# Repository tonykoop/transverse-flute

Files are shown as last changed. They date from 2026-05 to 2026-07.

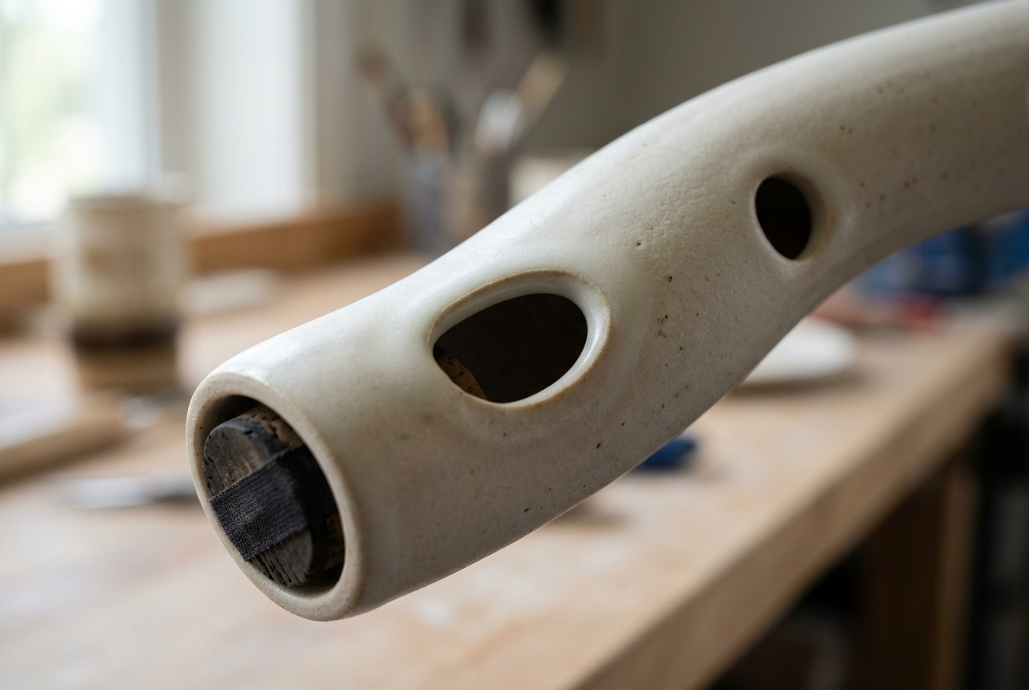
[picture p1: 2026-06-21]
images/macro/embouchure-edge.png

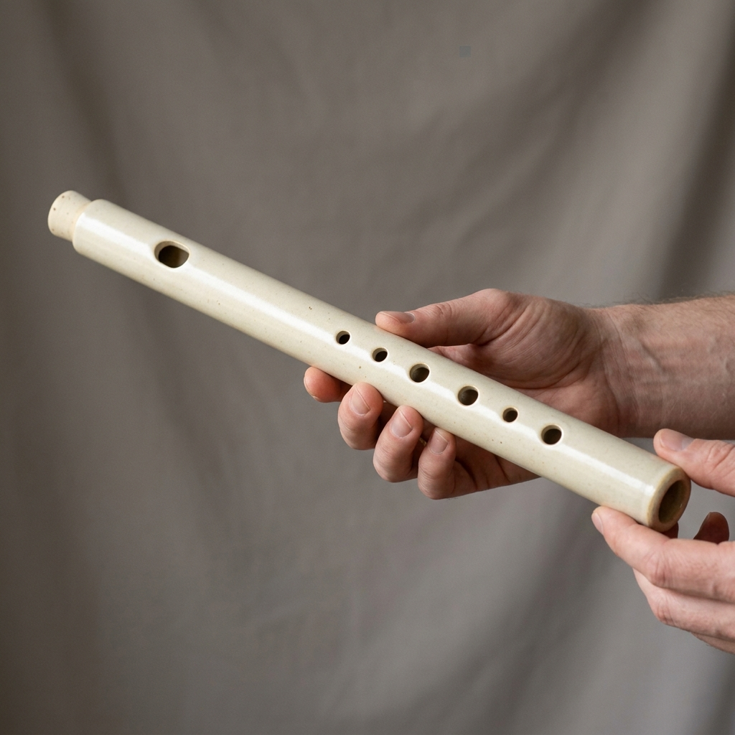
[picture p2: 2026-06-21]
images/hero-render.png

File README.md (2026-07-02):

# Transverse Flute - Experimental Slip-Cast Ceramic Flute Lab

> *A preparatory design repository for a family of slip-cast ceramic transverse flutes - unvalidated, intentionally provisional, and ready to become the project accelerator once materials and shop time arrive.*

Family overview drawing
*First-pass fired target family for D4, F4, G4, A4, and C5. These are planning dimensions, not proven instrument dimensions.*

## What this is

Engineering documentation for an **experimental slip-cast ceramic transverse flute family**. The idea is to start with target final fired dimensions, scale the build masters for X/Y/Z ceramic shrinkage, cast and fire the first round, measure what actually happened, then use those measurements to correct the second round.

This repository is not a finished portfolio of validated instruments yet. It is creative preparatory space: an accelerator, launchpad, laboratory notebook, design-control folder, and build packet so the project can move fast once supplies are acquired.

The repository combines:

1. **A parametric design workbook** ([`Slip-Cast-Transverse-Flute-Family.xlsx`](Slip-Cast-Transverse-Flute-Family.xlsx)) with fired target dimensions, provisional master scaling, tone-hole schedules, a DoE matrix, measurement tables, and shrink-factor fitting sheets.
2. **A Round 1 design-of-experiments plan** ([`doe-plan.md`](doe-plan.md)) for comparing clay bodies, wall targets, bore profiles, embouchure geometry, and mold/drain orientation.
3. **Shop-facing build documentation**: [`design.md`](design.md), [`mold-workflow.md`](mold-workflow.md), [`assembly-manual.md`](assembly-manual.md), [`validation.csv`](validation.csv), [`bom.csv`](bom.csv), [`sourcing.csv`](sourcing.csv), and [`supplier-rfq.md`](supplier-rfq.md).
4. **Drawings and starter CAD** in [`drawings/`](drawings/), [`cad/`](cad/), and [`cnc/`](cnc/) so the first physical work can move from sketch to master/mold planning without starting from a blank page.

Sister project to [`flutes`](https://github.com/tonykoop/flutes), [`fujara`](https://github.com/tonykoop/fujara), [`didgeridoo`](https://github.com/tonykoop/didgeridoo), [`tongue-drum`](https://github.com/tonykoop/tongue-drum), and the broader instrument workshop documentation in this GitHub folder.

## Status and validation warning

**Status:** L2 V5 build-packet candidate

V5 explorer/build-packet candidate for review; fabrication authority
is limited to first-pass prototype planning tables and the local OpenSCAD body
starter. The packet is **not build-ready as a validated instrument** and is not
L3/L4 measured or runtime-verified.

This design has **not been physically built, tuned, fired, or validated**. The dimensions are first-pass engineering targets based on open-open flute math, ceramic shrinkage assumptions, and Tony's existing flute design-table habits.

Use every number in this repository as one of:

- `target` - what the fired instrument is intended to become,
- `assumption` - what Round 1 is testing,
- `starting point` - what will be corrected after measurement.

The design is ready for preparation, quoting, sourcing, CAD cleanup, mold planning, and experimental setup. It is not ready to be treated as a proven flute recipe.

## Background - why slip casting changes the flute problem

A transverse flute is an open-open air column excited by a player blowing across an embouchure edge. In a wooden or metal flute, the maker can usually machine the bore and holes directly to final dimensions, then tune by controlled cutting, undercutting, or keywork adjustments.

Slip-cast ceramic adds a different engineering loop:

- the model/master is not the final size,
- wet clay, bone-dry clay, bisque, and glaze-fired ceramic each move differently,
- X/Y/Z shrinkage may not be equal,
- long thin tubes can sag or ovalize,
- wall buildup changes tone-hole chimney height,
- glaze can damage acoustic edges if it enters the embouchure, bore, or holes.

That makes this project a natural fit for a measured iteration cycle. Round 1 is mostly about learning the clay/process correction factors. Round 2 is where the design becomes more serious.

## Governing acoustic model

First-pass model:

```text
f = c / (2 * L_eff)
L_acoustic = c / (2 * f)
end_correction_total ~= 0.6 * bore_ID
sounding_length ~= L_acoustic - end_correction_total
hole_distance_from_foot ~= L_acoustic * (fundamental_frequency / hole_frequency)
```

This is enough to create a rational starting family, not enough to declare success. Embouchure shape, hole chimney height, wall thickness, bore roundness, stopper position, undercutting, and ceramic surface quality will all move the real instrument.

## The first design family

| ID | Key | Role | Fired pre-trim length | Initial master X @ 12% shrink |
| --- | --- | --- | ---: | ---: |
| SCF-D4-01 | D4 | Low reference / long-body risk case | 24.247 in | 27.554 in |
| SCF-F4-01 | F4 | Family interpolation check | 20.505 in | 23.301 in |
| SCF-G4-01 | G4 | Middle reference / likely first practical prototype | 18.388 in | 20.895 in |
| SCF-A4-01 | A4 | Family interpolation check | 16.432 in | 18.673 in |
| SCF-C5-01 | C5 | Soprano / short-body response check | 13.911 in | 15.808 in |

The detailed target table is in [`data/fired-dimension-targets.csv`](data/fired-dimension-targets.csv). The first-pass hole schedule is in [`data/hole-schedule.csv`](data/hole-schedule.csv).

## Shrinkage model

Coordinate convention:

- X = flute length, bore axis, embouchure station, and tone-hole stations.
- Y = side-to-side bore/OD width and horizontal hole dimensions.
- Z = vertical bore/OD height, wall buildup direction, sag, and ovalization.

The workbook starts at a deliberately provisional 12% shrink in each axis:

```text
master_x = fired_target_x / (1 - shrink_x)
master_y = fired_target_y / (1 - shrink_y)
master_z = fired_target_z / (1 - shrink_z)
observed_shrink_axis = 1 - fired_measured_axis / master_measured_axis
round2_master_axis = round1_master_axis * fired_target_axis / fired_measured_axis
```

Those values are placeholders until fired test bars, bore rings, and flute bodies are measured.

## Round 1 DoE

Round 1 is a screening study, not a production batch. It varies:

- key/scale: D4, G4, and C5 screening with F4/A4 family fill-ins,
- clay body: cone 6 stoneware and cone 6 porcelain,
- wall target: thin, nominal, and thick drain conditions,
- bore profile: cylindrical and mild taper,
- embouchure geometry: standard oval and longer oval,
- mold/drain orientation: horizontal and vertical.

Primary responses:

- X/Y/Z shrink,
- bore roundness and wall thickness,
- crack/warp/sag/seam outcomes,
- fundamental and scale-note cents error,
- octave response and breath threshold,
- subjective playability and tonal stability.

The run matrix is in [`data/doe-build-matrix.csv`](data/doe-build-matrix.csv).

## Engineering challenges this repository is meant to capture

**1. Translating additive-manufacturing shrink intuition into ceramic slip casting.** The project deliberately separates target fired dimensions from master dimensions, then treats X/Y/Z shrink as measured process data rather than a fixed catalog value.

**2. Keeping the acoustic model honest.** Open-open flute math gives the starting geometry, but ceramic flute behavior will be corrected from measured prototypes. The validation sheets are as important as the design table.

**3. Designing for a fragile long body before the materials are on hand.** The D4 body is long enough that mold strategy, drying support, seam cleanup, and bore ovalization are major design concerns before a single note is played.

**4. Creating a repository that becomes useful the moment supplies arrive.** This repo is the setup work: BOM, sourcing, RFQ, shop sequence, drawings, CAD starter, DoE protocol, and measurement schema.

## How to use this repository

Start here:

- [`print-packet.html`](print-packet.html) - browser-friendly combined packet for reading or printing.
- [`Slip-Cast-Transverse-Flute-Family.xlsx`](Slip-Cast-Transverse-Flute-Family.xlsx) - the parametric workbook and measurement hub.
- [`design.md`](design.md) - the compact engineering brief.
- [`doe-plan.md`](doe-plan.md) - the experimental plan.
- [`mold-workflow.md`](mold-workflow.md) - the slip-casting control plan.
- [`assembly-manual.md`](assembly-manual.md) - shop sequence from master through final validation.

Then, once supplies are acquired:

1. Date-check suppliers and update [`sourcing.csv`](sourcing.csv).
2. Pick the first Round 1 run from [`data/doe-build-matrix.csv`](data/doe-build-matrix.csv).
3. Make and measure the master.
4. Cast shrink bars, bore rings, and the flute body together.
5. Record measurements in [`data/prototype-measurements.csv`](data/prototype-measurements.csv).
6. Fit Round 2 corrections in [`data/shrinkage-fit.csv`](data/shrinkage-fit.csv).

## Repository structure

```text
transverse-flute/
|-- README.md
|-- LICENSE                    <- CC-BY 4.0
|-- Slip-Cast-Transverse-Flute-Family.xlsx
|-- design.md
|-- doe-plan.md
|-- mold-workflow.md
|-- assembly-manual.md
|-- bom.csv
|-- sourcing.csv
|-- supplier-rfq.md
|-- validation.csv
|-- cut-list.csv
|-- print-packet.md / print-packet.html
|-- capstone-deck.md
|-- data/
|   |-- fired-dimension-targets.csv
|   |-- hole-schedule.csv
|   |-- doe-build-matrix.csv
|   |-- prototype-measurements.csv
|   `-- shrinkage-fit.csv
|-- drawings/
|   |-- family-overview.svg
|   |-- mold-stack.svg
|   `-- SCF-*-body.svg
|-- cad/
|   `-- slip_cast_transverse_flute_body.scad
|-- cnc/
|   `-- master-fabrication-plan.md
|-- evolution/
|   |-- master/manifest.json
|   |-- design-intent.md
|   `-- revisions.md      <- Stage 0 evolution-pipeline intake (Gate A not yet run)
`-- scripts/
    `-- generate_packet.py
```

## Status

| Section | Status |
| --- | --- |
| Repo description and CC-BY license | done |
| Parametric workbook | first-pass generated |
| Fired target dimension table | first-pass generated |
| Tone-hole schedule | first-pass generated |
| Round 1 DoE plan | drafted |
| Mold workflow | drafted |
| Shop assembly manual | drafted |
| CAD body starter | preliminary OpenSCAD concept |
| Manufacturing drawings | SVG review drawings only |
| V5 family spec | added; open-open / both-ends-open assumptions explicit |
| Visual authority register | added; generated/concept outputs are not fabrication authority |
| MCP provenance log | present; no live MCP sessions were run for this lane |
| Evolution-pipeline intake | Stage 0 intake added (manifest, design-intent, revisions); Gate A not yet run |
| Supplier pricing and availability | not checked |
| Physical prototypes | not started |
| Fired shrink validation | no data yet |
| Acoustic validation | no data yet |
| Round 2 correction factors | pending Round 1 |

## License

Released under [CC-BY 4.0](LICENSE) - use freely with attribution. The written documentation, generated design tables, drawings, scripts, and experimental framework in this repository are my own preparatory engineering work. Because the instrument design is unvalidated, reuse should preserve the experimental status and measurement assumptions until physical builds prove otherwise.

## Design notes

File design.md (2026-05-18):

# Slip-Cast Transverse Flute Family Build Packet

## Source And Scope

- Date: `2026-05-02`
- Source workbook inspected: `/mnt/c/Users/Tony/Documents/Claude/Projects/Career/flutes-staging/Flutes-AI.xlsx`
- Relevant sheet: `Irish Flute`, which uses open-open flute math, D4 sanity dimensions, end correction, and 6-hole diatonic placement.
- Ceramic workflow references inspected: `Ocarina`, `Udu Drum Family`, and `vessel-flute-lab` build packets.

This packet is for unkeyed transverse ceramic flute prototypes made by slip casting. The acoustic dimensions below are final fired targets. Master and mold dimensions are scaled from those targets using provisional X/Y/Z shrink factors.

## Design Intent

Build a family across D4, F4, G4, A4, and C5 so the study sees both long-body casting behavior and smaller higher-key behavior. Round 1 is not trying to prove a finished product. It is meant to produce a clean data set:

- actual X/Y/Z fired shrink by material, wall, and mold orientation,
- actual bore roundness and wall buildup,
- pitch and response error against the open-open first-pass model,
- embouchure and bore-profile preferences before Round 2.

## Governing Model

First-pass open-open transverse flute model:

```text
f = c / (2 * L_eff)
L_acoustic = c / (2 * f)
end_correction_total ~= 0.6 * bore_ID
sounding_length ~= L_acoustic - end_correction_total
hole_distance_from_foot ~= L_acoustic * (fundamental_frequency / hole_frequency)
```

The hole positions are first-pass acoustic stations. Ceramic wall thickness, hole chimney height, undercutting, bore ovalization, embouchure geometry, and stopper position will move real pitch. The packet therefore makes hole cuts undersize and expects bisque-stage tuning.

The V5 acoustic-law summary is tracked in [`family-spec.csv`](family-spec.csv).
Every family row declares `acoustic_law=open_open`,
`end_condition=both_ends_open`, and `dimension_provenance=physics_derived`.
Those fields describe the first-pass planning model only; measured prototype
pitch, bore roundness, shrink, and tone-hole correction data are still required
before the dimensions become validated tuning authority.

## Initial Family Targets

| ID | Key | Bore ID | OD | Sounding length | Pre-trim fired length | Master X length @12% |
| --- | --- | ---: | ---: | ---: | ---: | ---: |
| SCF-D4-01 | D4 | 0.748 in | 1.028 in | 22.625 in | 24.247 in | 27.554 in |
| SCF-F4-01 | F4 | 0.669 in | 0.939 in | 19.001 in | 20.505 in | 23.301 in |
| SCF-G4-01 | G4 | 0.669 in | 0.929 in | 16.885 in | 18.388 in | 20.895 in |
| SCF-A4-01 | A4 | 0.591 in | 0.841 in | 15.045 in | 16.432 in | 18.673 in |
| SCF-C5-01 | C5 | 0.512 in | 0.742 in | 12.643 in | 13.911 in | 15.808 in |

## Shrinkage Model

Coordinate convention:

- X = flute length/bore axis/hole stations.
- Y = side-to-side bore and outside width.
- Z = vertical height, wall buildup, and ovalization direction.

```text
master_x = fired_target_x / (1 - shrink_x)
master_y = fired_target_y / (1 - shrink_y)
master_z = fired_target_z / (1 - shrink_z)
observed_shrink_axis = 1 - fired_measured_axis / master_measured_axis
round2_master_axis = round1_master_axis * fired_target_axis / fired_measured_axis
```

Initial assumption is `shrink_x = shrink_y = shrink_z = 0.12`. This is a placeholder, not a material claim.

## Round 1 Success Criteria

- No full-length cracking through drying, bisque, or glaze fire.
- Bore remains measurable and cleanable.
- Embouchure speaks a stable fundamental and octave on at least the G4 or C5 prototypes.
- Hole tuning can be brought within +/-35 cents after bisque without grotesque hole enlargement.
- X/Y/Z shrink measurements have enough consistency to choose Round 2 scale factors.

## Round 2 Decision Path

1. Fit shrink_x, shrink_y, and shrink_z from bars, bore rings, and flute features.
2. Choose the best material/profile/embouchure combination from the DoE.
3. Update the workbook inputs and regenerate master dimensions.
4. Rebuild the full five-key family using corrected X/Y/Z scale factors.
5. Tighten acceptance to +/-10 cents for tuned notes and +/-0.010 to +/-0.030 in on critical fired dimensions.

## Open Assumptions

- Bore diameters are adapted from the existing Irish/simple-system flute design range, then made ceramic-friendly with thinner walls than wood.
- A removable head stopper or cork test plug is assumed for Round 1 because it gives a reversible tuning variable.
- All prices, supplier availability, and exact clay data must be date-checked before buying.
- CAD mold release and split lines need confirmation in the actual CAD model before cutting production molds.

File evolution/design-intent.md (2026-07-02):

# Design Intent — transverse-flute rev A

- Master CAD: `cad/slip_cast_transverse_flute_body.scad` (sha256: 09559ce3695fb347a80539320d67dd08b2f200aac15d973c2522a8109cbf1eda), driven by `Slip-Cast-Transverse-Flute-Family.xlsx` (sha256: 8956d4db48cb64065a868b3e6a1f89d63ca9b68a0c0be8512c7b77fd6ee7f224)
- Function: Experimental slip-cast ceramic transverse flute family (D4/F4/G4/A4/C5). Open-open flute model: both ends open, side-blown embouchure; pitch from sounding length + bore + end corrections. Tone-hole stations are first-pass open-open ratios and require prototype tuning. First-pass workflow: fired target dims → scale masters for shrinkage → cast/fire Round 1 → measure → correct.
- Environment: Cone-6 slip-cast ceramic via master + plaster mold; long thin tubes are warp/crack-prone in firing; shrinkage is an assumption until a clay test bar is measured. Embouchure/voicing geometry is empirical and outside the model.
- Target qty: 1 (Round 1 prototype, G4 first). Deadline: TBD. Budget/unit ceiling: TBD.

## Critical dimensions (carry tolerances)

| Feature | Nominal | Tolerance | Why critical | Source |
| --- | --- | --- | --- | --- |
| G4 packet sounding length | 428.88 mm | tune to pitch after firing | fundamental pitch (G4 = 391.995 Hz) | family-spec.csv SCF-G4-01 (physics_derived) |
| G4 fired bore ID | 16.99 mm | measure after fire | bore governs pitch/response | family-spec.csv SCF-G4-01 (physics_derived) |
| G4 total end correction | 10.19 mm | recompute from measured bore | open-open end effect | family-spec.csv SCF-G4-01 |
| G4 master overall length (initial) | 530.73 mm | recompute from measured shrinkage | fired size vs master | family-spec.csv SCF-G4-01 (first-pass scaling) |
| Tone-hole stations | per data/hole-schedule.csv (first-pass ratios) | undersize; tune post-bisque | scale intonation | data/hole-schedule.csv (measurement_required) |
| A4 reference | 440.000 Hz | ±cents logged in validation.csv | tuning correctness | family-spec.csv SCF-A4-01 |

## Incidental (free for DFM)

- Body exterior styling, decorative banding, glaze color/family, non-mating surface finish, headjoint cosmetic contour.

## Must-nots (DFM may never violate)

- Embouchure/voicing cut is tuning-sensitive: never freeze it from the table or a lossy mesh export — refine by hand and log (risks.md / README).
- Keep tone holes undersized before empirical bisque-stage tuning (data/hole-schedule.csv; risks.md Acoustic).
- Do not treat any dimension as proven until logged in validation.csv; no build/tune/fire has occurred (README validation warning).
- Do not scale to the full family before Round 1 (G4) measured shrinkage + tuning corrections (doe-plan.md / risks.md Structural).

## Material intent

- Preferred: Cone-6 slip-cast ceramic; master + two-piece plaster mold (per bom.csv / mold-workflow.md).
- Acceptable subs: per sourcing.csv / supplier-rfq.md (spec-first; live prices unverified; mouth-safe finishes only).
- Forbidden: non-mouth-safe interior finishes on blown bodies.

## Stage status

Stage 0 intake complete 2026-07-01. Gate A (Alpha shop compile) NOT yet run — no concessions logged, nothing presented as shippable. Design is experimental/unvalidated; fabrication authority remains measurement-gated (L2 candidate for review).

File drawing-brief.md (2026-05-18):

# Drawing Brief

## Required Views

- Family overview showing D4, F4, G4, A4, and C5 fired target lengths.
- Individual body plan view for each key with X-axis datum, embouchure, tone holes, bore ID, OD, and fired/master length notes.
- Section view at embouchure showing wall thickness, bore, hole edge, undercut zone, and stopper relationship.
- Section view through a tone hole showing chimney height and allowed tuning/undercut area.
- Mold stack view showing split line, registration keys, pour/drain direction, seam cleanup zone, and optional three-piece D4 strategy.
- Shrink coupon drawing with X/Y/Z labels and measurement flats.

## Critical Dimensions

| Dimension | Source | Tolerance Intent |
| --- | --- | --- |
| Fired sounding length | `data/fired-dimension-targets.csv` and workbook | Tuning critical |
| Embouchure center from head | workbook, initial 1.5 x bore ID | Response and tuning |
| Bore ID Y/Z | workbook and bore ring measurement | Tuning, response, shrink fit |
| Tone-hole stations X | `data/hole-schedule.csv` | Tuning critical; first-pass only |
| Tone-hole diameters | `data/hole-schedule.csv` | Cut undersize; tune after bisque |
| Wall thickness | DoE wall target and measured coupons | Durability, weight, hole chimney |
| Master X/Y/Z scale | shrink model | Process critical |

## Existing Drawings

- `drawings/family-overview.svg`
- `drawings/mold-stack.svg`
- `drawings/SCF-D4-01-body.svg`
- `drawings/SCF-F4-01-body.svg`
- `drawings/SCF-G4-01-body.svg`
- `drawings/SCF-A4-01-body.svg`
- `drawings/SCF-C5-01-body.svg`

These are SVG shop-review drawings. They are not a substitute for final CAD mold drawings with draft and release analysis.

## V5 Visual Authority

The visual authority chain is tracked in
[`visual-output-register.csv`](visual-output-register.csv). The design tables
and OpenSCAD starter are first-pass prototype fabrication authority for current
planning geometry only. The SVG drawings are derived review previews and must
not be treated as standalone cut-ready DXF/CNC authority. No generated image is
dimensional authority for bore length, embouchure geometry, tone-hole position,
wall thickness, mold split lines, or toolpaths.

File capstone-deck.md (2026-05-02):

# Slip-Cast Transverse Flute Family
- Musical instrument documentation capstone
- Packet: /mnt/c/Users/Tony/Documents/GitHub/transverse-flute
- Generated: 2026-05-02

---

# How To Use This Packet
- Start with design.md for intent and assumptions.
- Use bom.csv, sourcing.csv, and cut-list.csv before buying or cutting.
- Use drawing-brief.md and CAD/CNC folders before machining.
- Print the packet for shopping, shop work, and validation.

---

# File Map
- design.md: Project intent, catalog metadata, assumptions, and validation plan.
- bom.csv: Starter bill of materials with part categories, quantities, drawing refs, and notes.
- sourcing.csv: Supplier/search tracker with specs, price/date fields, lead time, substitutes, and risks.
- cut-list.csv: Rough/final stock sizes, material, grain/orientation, operations, yield, and offcuts.
- drawing-brief.md: Manufacturing drawing and technical product sketch brief.
- assembly-manual.md: Shop-facing sequence, tools, fixtures, safety, tuning, finishing, and maintenance notes.
- validation.csv: Target/measured values, tolerance, environment, result, and tuning/build action log.
- supplier-rfq.md: Supplier email/request-for-quote starter.

---

# Build Workflow
- Design and assumptions
- Source materials and hardware
- Prepare stock, fixtures, and CNC/laser/lathe setup
- Assemble, tune, finish, and validate

---

# Sourcing And BOM
- BOM gives part categories and drawing references.
- Sourcing tracks search terms, supplier candidates, price/date, lead time, and substitutions.
- Visual BOM brief turns the parts list into a presentation-ready image board.

---

# Shop Packet
- Cut list for lumber/sheet/blank planning.
- Assembly manual for away-from-keyboard work.
- Validation sheet for measured dimensions, tuning, and pass/fail checks.

---

# Drawings, CAD, CNC
- drawing-brief.md defines required views, dimensions, datums, and sketch intent.
- cad/ holds models and design tables.
- cnc/ holds CAM, toolpaths, setup sheets, and dry-run notes.
- drawings/ holds PDFs, SVGs, DXFs, and drawing exports.

---

# Images And Screenshots
- Add hero render/photo, visual BOM, shop screenshots, drawing previews, and validation photos in images/.

---

# Next Actions
- Replace TBDs with measured/source-backed values.
- Verify live supplier price and availability before buying.
- Export final drawings and visual BOM images.
- Regenerate this deck and print packet after final edits.

---

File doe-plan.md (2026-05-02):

# Round 1 DoE Plan

## Purpose

Round 1 is a screening study for a slip-cast transverse flute family. It should answer:

- What are the actual X/Y/Z shrink factors for each clay/process condition?
- Which clay body and wall target survive long flute geometry?
- Does a cylindrical bore or mild taper give better response after ceramic firing?
- Which embouchure geometry speaks cleanly before excessive hand correction?
- Do shrink and acoustic errors interpolate across D4, G4, and C5 well enough to build F4 and A4 in Round 2?

## Factors

| Factor | Levels |
| --- | --- |
| Key/scale | D4, G4, C5 screening; F4 and A4 family fill-ins |
| Clay body | Cone 6 stoneware, Cone 6 porcelain |
| Wall target | thin drain, nominal drain, thick drain |
| Bore profile | cylindrical, mild taper |
| Embouchure | standard oval, longer oval |
| Mold orientation | horizontal drain, vertical drain |

## Responses

- X/Y/Z shrink from bars, bore rings, and flute features.
- Bore roundness: fired ID Y vs ID Z.
- Wall thickness at head, middle, foot.
- Fundamental and six-finger scale cents error.
- Octave response, breath threshold, tone stability, and subjective playability.
- Crack/warp/sag/seam cleanup outcomes.

## Round 1 Matrix

See `data/doe-build-matrix.csv`. It contains 20 planned runs including screening and family fill-in builds.

## Round 2 Fit

Use `data/prototype-measurements.csv` and `data/shrinkage-fit.csv` to compute:

```text
shrink_axis = 1 - fired_axis / master_axis
round2_axis_scale_multiplier = target_fired_axis / measured_fired_axis
cents_error = 1200 * log2(measured_frequency / target_frequency)
```

If material or orientation creates a strong interaction, keep separate shrink factors by material/orientation rather than forcing a single global X/Y/Z value.

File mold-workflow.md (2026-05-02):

# Slip-Cast Mold Workflow

## Master Strategy

1. Generate the master from the workbook/CAD dimensions using X/Y/Z scale factors.
2. Add external handling tabs, pour/drain reservoir geometry, and mold keys outside the final fired acoustic envelope.
3. Seal and polish the master. Measure master X/Y/Z dimensions before making plaster.
4. Mark datums permanently: head end, foot end, top/embouchure side, X/Y/Z axes, split line, and build ID.

## Mold Strategy

- Use a two-piece mold for G4/A4/C5 if release is clean.
- Consider a three-piece or sectional mold for D4 because length, sag, and demold stress are the main risks.
- Mold center marks or shallow dimples for holes are useful; avoid fully molded tone holes in Round 1 unless release testing proves they are clean.
- Keep registration keys away from the bore axis, embouchure edge, hole centers, and seam-cleanup surfaces.
- Include a pour/drain reservoir that can be removed without touching the fired trim target.

## Casting Controls

Record these for every run:

- slip body and batch,
- mold dry weight and mold age,
- pour time, drain time, and drain orientation,
- room temperature and humidity,
- leather-hard demold time,
- wall thickness at sacrificial rim/coupon,
- dry, bisque, and glaze firing schedules,
- fired mass, length, bore Y/Z, OD Y/Z, and note frequencies.

## Tuning-Friendly Hole Strategy

1. Cast the body with molded center marks only.
2. Cut pilot holes at leather hard, about 85% of the shrink-compensated target diameter.
3. Dry and bisque.
4. Tune by opening holes with diamond tools. Stop before final glaze.
5. Wax resist all acoustic edges before glaze.

## Failure Modes To Watch

- Long D4 body sags or twists while drying.
- Bore ovalizes differently in Y and Z.
- Mold seam intrudes into the embouchure or tone-hole region.
- Wall thickness drifts with drain time enough to change hole chimney height.
- Glaze softens, rounds, or chokes the embouchure and tone-hole edges.

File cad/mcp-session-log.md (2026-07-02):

# MCP Session Log

This log is intentionally present for the V5 provenance contract. No live MCP
tool sessions were run in this Round 30 lane, so no generated render, Adobe,
Blender, Illustrator, Photoshop, or image-gen artifact is claimed here.

| timestamp_utc | mcp_tool | session_id | artifact | parent_artifact | authority_role | notes |
| --- | --- | --- | --- | --- | --- | --- |
| 2026-05-18T00:00:00Z | none | not-run-round30 | cad/slip_cast_transverse_flute_body.scad | data/fired-dimension-targets.csv | local-cad-starter | Existing OpenSCAD starter reconciled to the G4 first-pass target; not a measured or runtime-generated MCP artifact. |
| 2026-07-01T00:00:00Z | claude-code (Fable 5) | fable-v5-refresh-2026-07-01 | Slip-Cast-Transverse-Flute-Family.xlsx, data/hole-schedule.csv, data/fired-dimension-targets.csv | Slip-Cast-Transverse-Flute-Family.xlsx | packet_refresh (authority_result=fabrication, review_status=self_checked) | V5 refresh pass; tabular packet data (workbook + hole schedule + fired-dimension targets) reviewed against design table. No dimension changes made. Provenance rows added to satisfy V5 fabrication-artifact logging. |
| 2026-07-01T00:00:00Z | claude-code (Fable 5) + OpenSCAD CLI | fable-v5-refresh-2026-07-01 | cad/slip_cast_transverse_flute_body.scad | data/fired-dimension-targets.csv | cad_authoring (authority_result=pending_measurement, review_status=self_checked) | Existing parametric body-envelope master (kept, not rewritten). openscad render check: pass (openscad -o STL, exit 0). |
| 2026-07-01T00:00:00Z | claude-code (Fable 5) | fable-v5-refresh-2026-07-01 | transverse-flute-starter.wl | Slip-Cast-Transverse-Flute-Family.xlsx | analysis_source (authority_result=derived_preview, review_status=unreviewed) | Wolfram/physics starter; source-only (not executed). L2 evidence. |

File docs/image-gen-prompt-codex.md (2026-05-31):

# Image Generation Prompt

Concept image only; not fabrication authority. Do not include cut-ready dimensions, hole locations, mold split dimensions, or toolpaths.

## Hero Prompt

Photorealistic 3/4 studio product photograph of an experimental slip-cast ceramic transverse flute family, unkeyed and open-hole, with D4, F4, G4, A4, and C5 prototypes arranged from longest to shortest. Show smooth fired ceramic bodies with subtle stoneware and porcelain glaze variations, oval embouchure holes, undersize tone holes, removable stopper cues, and faint mold seam cleanup consistent with a lab prototype. Clean neutral background, soft directional studio lighting, realistic fragile ceramic scale cues, high detail, 50mm lens look.

## In-Context Prompt

Photorealistic ceramic studio scene with slip-cast transverse flute prototypes on a ware board beside plaster molds, shrinkage test bars, bore rings, calipers, clay slip container, and a tuning notebook. Natural studio light, practical experimental mood, showing the project as a fired-dimension and shrinkage study rather than a finished production flute line.

## Detail / Macro Prompt

Macro photorealistic close-up of a ceramic transverse flute embouchure: smooth oval cut, fired clay wall thickness, subtle glaze edge kept out of the acoustic opening, faint mold seam cleanup, and a nearby undersize tone hole. Use shallow depth of field, realistic ceramic texture, and no dimensional marks.

## Negative / Avoid

No text, no watermarks, no brand logos, no extra limbs, anatomically plausible hands if shown, no metal keywork, no impossible glaze inside holes, no hole-location diagrams, no dimensions, no toolpaths.

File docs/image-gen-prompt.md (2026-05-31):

# Image-Gen Prompts

Concept image only; not fabrication authority. Do not include cut-ready dimensions, hole locations, tone-hole spacing, bore diameters, sounding lengths, shrink factors, or toolpaths.

## Hero Prompt

Photorealistic 3/4 product photograph of a finished slip-cast ceramic transverse flute: a single long, slender cylindrical tube held horizontally, open at both ends like a concert flute, its surface the smooth fired glaze of cone-6 stoneware or porcelain with the soft sheen of a kiln-fired clay body rather than wood or metal. The defining feature is the oval embouchure hole set near one end where the player blows across the edge, with a hint of a removable head stopper just beyond it; a single in-line row of round, unkeyed finger tone holes runs down the body, the instrument having no metal keywork at all so it reads as a clean simple-system ceramic flute. The fired ceramic implies a faintly weighty, fragile elegance with a gently rounded bore mouth at each open end, restrained surface with no decoration. Hand-playable flute scale cues, satin glazed ceramic catching soft directional studio light that grazes the curved tube, clean neutral studio background, 3/4 product-photography angle, ~50mm lens, high detail, photorealistic, no text labels. Avoid: no text, logos, watermarks, or fake maker marks, no dimension callouts or cut diagrams, no metal keys or pads, no impossible bends in the tube, no glaze flooding the embouchure or tone holes. IMPORTANT: This image is a concept visualization only. Do not include dimension lines, measurements, or fabrication specifications. The image is not authoritative for any physical build dimension.

## In-Context Prompt

Photorealistic image of the slip-cast ceramic transverse flute family staged on a quiet ceramic-studio bench: five finished fired flutes of graduated length fanned in a row from the longest low-D body down to the short soprano-C body, arranged like a tonal scale, beside a plaster mold half, a couple of small fired shrink-test coupons and a bore ring, and a chromatic tuner with a clip mic for storytelling. Natural window light rakes across the glazed tubes; a maker's hands hover above the middle flute as if checking the embouchure against the tuner, the longest body resting on a felt pad so its slender fragility reads clearly. Warm workshop atmosphere, dusty plaster and clay tones in the background, realistic fired-ceramic materials, shallow depth of field, concept visualization only. Avoid: no text, logos, watermarks, or fake maker marks, no dimension callouts, no metal keywork, no impossible mechanisms; anatomically plausible hands with natural finger placement over the tone holes. IMPORTANT: This image is a concept visualization only. Do not include dimension lines, measurements, or fabrication specifications. The image is not authoritative for any physical build dimension.

## Detail Prompt

Photorealistic macro close-up of the signature mechanism: the oval embouchure hole of the ceramic flute where the player blows across a crisp acoustic edge, the fired glaze sweeping smoothly into the cleanly cut hole with no glaze pooling on the edge, the subtle shadow of the bore and a hint of the removable head stopper visible just inside the open end, one or two round unkeyed tone holes blurring into the body beyond. Satin glazed cone-6 ceramic texture with faint kiln character, the curved wall of the tube catching soft raking light that reveals the rounded mouth of the open end and the chimney of the tone hole through the wall thickness. Shallow depth of field, high detail, no measurements. Avoid: no text, logos, watermarks, or fake maker marks, no dimension callouts, no metal keys or pads, no impossible edges, no glaze flooding the embouchure. IMPORTANT: This image is a concept visualization only. Do not include dimension lines, measurements, or fabrication specifications. The image is not authoritative for any physical build dimension.

## Negative / Avoid

No text, logos, watermarks, fake maker marks, cut diagrams, dimension callouts, metal keywork or pads, impossible tube bends, glaze flooding the embouchure or tone holes, extra fingers, or hands covering tone holes unnaturally; anatomically plausible hands if a player is shown.

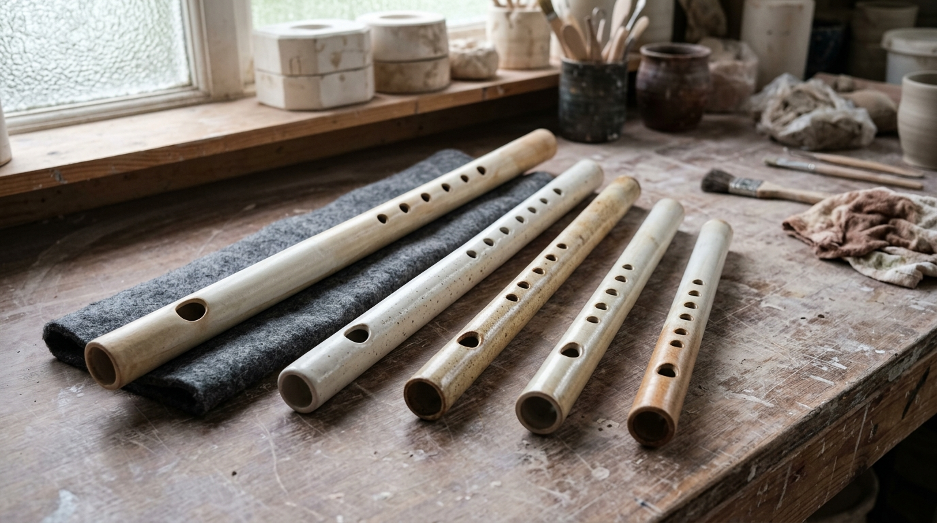
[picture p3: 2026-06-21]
images/family-group.png

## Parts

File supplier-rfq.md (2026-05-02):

# Supplier RFQ Starter

Subject: RFQ - slip-cast ceramic flute prototype materials and master/mold support

Hello,

I am prototyping a family of slip-cast ceramic transverse flutes and need materials or fabrication support with measured shrinkage and repeatability data.

Please quote the following where available:

- Cone 6 stoneware casting slip with shrinkage, absorption, and firing schedule data.
- Cone 6 porcelain casting slip with shrinkage, absorption, and firing schedule data.
- Pottery plaster suitable for slip-casting molds.
- Optional high-resolution master printing or machining for long cylindrical flute masters up to about 29 in master length.

Please include:

- unit price and minimum order,
- current availability and lead time,
- shipping or local pickup options,
- technical data sheets,
- recommended mold/drying/firing notes,
- any substitutions you recommend for thin-walled musical instrument bodies.

The prototypes will be measured for X/Y/Z shrinkage, bore roundness, wall thickness, and acoustic tuning after firing.

Thank you,

Tony

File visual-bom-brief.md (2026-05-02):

# Visual BOM Brief

Create an image-forward BOM plate in Tony's Ashiko BOM style:

- Header: Slip-Cast Transverse Flute Family, quote date, material status, and Round 1 / Round 2 label.
- Hero image: family fan of the five fired target flutes or a clean CAD render.
- Table rows grouped by CAD/master, mold, ceramic material, tuning tools, validation tools, and finishing.
- Include thumbnails for: master, plaster mold halves, casting slip, shrink bars, bore rings, diamond files, tuner/mic, cork/stopper kit.
- Add callouts showing X/Y/Z shrink axes and where measurements are taken.
- Mark generated/CAD imagery as placeholders until replaced with shop photos or supplier images.

Important: the visual BOM should communicate process and parts, not invent unverified dimensions. Pull all numbers from the workbook and CSVs.

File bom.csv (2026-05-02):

item_id | subsystem | item | qty | unit | material_spec | make_buy | drawing_ref | notes
SCF-BOM-001 | CAD/master | Parametric flute body master set | 5 | masters | Sealed 3D print or machined master, scaled by X/Y/Z shrink factors | Make | drawings/SCF-*-body.svg; cad/slip_cast_transverse_flute_body.scad | Use as mold masters or CAD reference. Add mold split before production tooling.
SCF-BOM-002 | Mold | Two-piece or three-piece plaster molds | 5+ | molds | Pottery plaster, registration keys, pour/drain reservoir | Make | drawings/mold-stack.svg | D4 may need sectional mold or reinforced cradle due to length.
SCF-BOM-003 | Material | Cone 6 stoneware casting slip | TBD | gallons | Casting slip with known fired shrinkage and absorption | Buy/mix | data/doe-build-matrix.csv | Date-check supplier and record batch number.
SCF-BOM-004 | Material | Cone 6 porcelain casting slip | TBD | gallons | Porcelain slip for comparison runs | Buy/mix | data/doe-build-matrix.csv | Higher shrink/warpage risk, better density and surface.
SCF-BOM-005 | Tuning | Diamond needle files and small diamond burrs | 1 | set | Fine files for bisque and fired ceramic hole tuning | Buy | assembly-manual.md | Avoid glazing acoustic edges after tuning.
SCF-BOM-006 | Validation | Measurement kit | 1 | kit | Calipers, bore gauges/pin gauges, tuner, mic, thermometer/hygrometer, scale | Use/buy | validation.csv | Use the same tuner/mic distance for all response tests.
SCF-BOM-007 | Voicing | Cork/stopper test kit | 5 | sets | Cork, silicone, or printed plug for head-end tuning experiments | Make/buy | drawing-brief.md | Treat head-stopper position as an adjustable variable before ceramic-integral solutions.
SCF-BOM-008 | Finish | Wax resist and glaze test set | 1 | set | Food-safe/contact-safe glaze where mouth contact occurs; acoustic edges waxed clear | Buy | mold-workflow.md | Keep glaze out of embouchure, bore, tone holes, and stopper fit surfaces.

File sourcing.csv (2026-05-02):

source_id | category | spec | supplier_or_search_terms | qty | date_checked | unit_price | lead_time | substitution_rule | risk_notes
SRC-SLIP-STONEWARE | Ceramic slip | Cone 6 stoneware casting slip, published shrinkage and absorption data | local ceramic supplier cone 6 stoneware casting slip shrinkage data sheet | TBD |  |  |  | Must have measured or published shrinkage; color can vary. | Live price and availability intentionally blank until purchase planning.
SRC-SLIP-PORCELAIN | Ceramic slip | Cone 6 porcelain casting slip, low warpage preferred | cone 6 porcelain casting slip shrinkage casting data sheet | TBD |  |  |  | Substitute only with data-backed shrink and firing schedule. | Porcelain may move more; use bars and rings before long D4 molds.
SRC-PLASTER | Mold material | Pottery plaster or high-strength mold plaster | USG pottery plaster No. 1 local ceramic supplier | TBD |  |  |  | Must be absorbent mold plaster, not general patching plaster. | Mold drying time affects casting wall thickness and repeatability.
SRC-PRINT | Master fabrication | High-resolution sealed print or machined master; smooth bore core strategy | SLA print service large format resin smooth finish or in-house FDM sealed master | 5 masters plus coupons |  |  |  | Any method is acceptable if master dimensions are measured and sealed. | Layer lines transfer to plaster and may disturb mold release.
SRC-TUNING | Tuning tools | Diamond needle files, small diamond burrs, tuner/mic | diamond needle file set ceramic tuning burr chromatic tuner measurement microphone | 1 kit |  |  |  | Prefer fine controlled abrasion over aggressive rotary cutting. | Over-opening holes is not reversible.

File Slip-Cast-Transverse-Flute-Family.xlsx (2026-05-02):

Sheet: Inputs
Slip-Cast Transverse Flute Family Inputs
Generated | 2026-05-02
Source basis | Open-open flute model adapted from Tony's Flutes-AI.xlsx Irish Flute sheet
A4_Hz | 440
speed_of_sound_in_per_s_68F | 13552
shrink_x_initial | 0.12 | X axis = bore length and hole stations
shrink_y_initial | 0.12 | Y axis = side-to-side bore/OD and hole width
shrink_z_initial | 0.12 | Z axis = vertical OD/wall/ovalization
round2_rule | new_master_axis = old_master_axis * target_fired_axis / measured_fired_axis

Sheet: Fired Targets
instrument_id | variant | key | midi | fundamental_hz | bore_id_fired_in | wall_fired_in | od_fired_in | acoustic_length_in | end_correction_total_in | sounding_length_in | head_margin_in | foot_trim_band_in | pretrim_overall_fired_in | embouchure_x_len_fired_in | embouchure_y_width_fired_in
SCF-D4-01 | Low D reference | D4 | 62 |  | 0.748 | 0.14 |  |  |  |  |  | 0.5
SCF-F4-01 | F middle | F4 | 65 |  | 0.669 | 0.135 |  |  |  |  |  | 0.5
SCF-G4-01 | G middle | G4 | 67 |  | 0.669 | 0.13 |  |  |  |  |  | 0.5
SCF-A4-01 | A small alto | A4 | 69 |  | 0.591 | 0.125 |  |  |  |  |  | 0.5
SCF-C5-01 | C soprano | C5 | 72 |  | 0.512 | 0.115 |  |  |  |  |  | 0.5

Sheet: Master Scale
instrument_id | master_overall_x_in | master_bore_y_in | master_od_y_in | master_od_z_in | master_emb_x_in | master_emb_y_in | formula_note
SCF-D4-01 |  |  |  |  |  |  | Update Inputs B7:B9 after Round 1 measurement.
SCF-F4-01 |  |  |  |  |  |  | Update Inputs B7:B9 after Round 1 measurement.
SCF-G4-01 |  |  |  |  |  |  | Update Inputs B7:B9 after Round 1 measurement.
SCF-A4-01 |  |  |  |  |  |  | Update Inputs B7:B9 after Round 1 measurement.
SCF-C5-01 |  |  |  |  |  |  | Update Inputs B7:B9 after Round 1 measurement.

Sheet: Hole Schedule
instrument_id | key | hole_no | interval | target_note | target_frequency_hz | fired_center_from_foot_in | fired_center_from_head_in | fired_hole_diameter_in | leather_hard_pilot_dia_in_85pct | notes
SCF-D4-01 | D4 | 1 | 2 | E4 | 329.628 | 20.557 | 3.191 | 0.254 | 0.246 | First-pass station; cut undersize and tune after bisque.
SCF-D4-01 | D4 | 2 | 4 | Gb4 | 369.994 | 18.314 | 5.433 | 0.269 | 0.26 | First-pass station; cut undersize and tune after bisque.
SCF-D4-01 | D4 | 3 | 5 | G4 | 391.995 | 17.286 | 6.461 | 0.284 | 0.275 | First-pass station; cut undersize and tune after bisque.
SCF-D4-01 | D4 | 4 | 7 | A4 | 440 | 15.4 | 8.347 | 0.299 | 0.289 | First-pass station; cut undersize and tune after bisque.
SCF-D4-01 | D4 | 5 | 9 | B4 | 493.883 | 13.72 | 10.027 | 0.322 | 0.311 | First-pass station; cut undersize and tune after bisque.
SCF-D4-01 | D4 | 6 | 11 | Db5 | 554.365 | 12.223 | 11.524 | 0.344 | 0.332 | First-pass station; cut undersize and tune after bisque.
SCF-F4-01 | F4 | 1 | 2 | G4 | 391.995 | 17.286 | 2.719 | 0.227 | 0.22 | First-pass station; cut undersize and tune after bisque.
SCF-F4-01 | F4 | 2 | 4 | A4 | 440 | 15.4 | 4.605 | 0.241 | 0.233 | First-pass station; cut undersize and tune after bisque.
SCF-F4-01 | F4 | 3 | 5 | Bb4 | 466.164 | 14.536 | 5.469 | 0.254 | 0.246 | First-pass station; cut undersize and tune after bisque.
SCF-F4-01 | F4 | 4 | 7 | C5 | 523.251 | 12.95 | 7.055 | 0.268 | 0.258 | First-pass station; cut undersize and tune after bisque.
SCF-F4-01 | F4 | 5 | 9 | D5 | 587.33 | 11.537 | 8.468 | 0.288 | 0.278 | First-pass station; cut undersize and tune after bisque.
SCF-F4-01 | F4 | 6 | 11 | E5 | 659.255 | 10.278 | 9.727 | 0.308 | 0.297 | First-pass station; cut undersize and tune after bisque.
SCF-G4-01 | G4 | 1 | 2 | A4 | 440 | 15.4 | 2.488 | 0.227 | 0.22 | First-pass station; cut undersize and tune after bisque.
SCF-G4-01 | G4 | 2 | 4 | B4 | 493.883 | 13.72 | 4.168 | 0.241 | 0.233 | First-pass station; cut undersize and tune after bisque.
SCF-G4-01 | G4 | 3 | 5 | C5 | 523.251 | 12.95 | 4.938 | 0.254 | 0.246 | First-pass station; cut undersize and tune after bisque.
SCF-G4-01 | G4 | 4 | 7 | D5 | 587.33 | 11.537 | 6.351 | 0.268 | 0.258 | First-pass station; cut undersize and tune after bisque.
SCF-G4-01 | G4 | 5 | 9 | E5 | 659.255 | 10.278 | 7.61 | 0.288 | 0.278 | First-pass station; cut undersize and tune after bisque.
SCF-G4-01 | G4 | 6 | 11 | Gb5 | 739.989 | 9.157 | 8.731 | 0.308 | 0.297 | First-pass station; cut undersize and tune after bisque.
SCF-A4-01 | A4 | 1 | 2 | B4 | 493.883 | 13.72 | 2.212 | 0.201 | 0.194 | First-pass station; cut undersize and tune after bisque.
SCF-A4-01 | A4 | 2 | 4 | Db5 | 554.365 | 12.223 | 3.709 | 0.213 | 0.206 | First-pass station; cut undersize and tune after bisque.
SCF-A4-01 | A4 | 3 | 5 | D5 | 587.33 | 11.537 | 4.395 | 0.225 | 0.217 | First-pass station; cut undersize and tune after bisque.
SCF-A4-01 | A4 | 4 | 7 | E5 | 659.255 | 10.278 | 5.654 | 0.236 | 0.228 | First-pass station; cut undersize and tune after bisque.
SCF-A4-01 | A4 | 5 | 9 | Gb5 | 739.989 | 9.157 | 6.775 | 0.254 | 0.245 | First-pass station; cut undersize and tune after bisque.
SCF-A4-01 | A4 | 6 | 11 | Ab5 | 830.609 | 8.158 | 7.774 | 0.272 | 0.263 | First-pass station; cut undersize and tune after bisque.
SCF-C5-01 | C5 | 1 | 2 | D5 | 587.33 | 11.537 | 1.874 | 0.174 | 0.168 | First-pass station; cut undersize and tune after bisque.
SCF-C5-01 | C5 | 2 | 4 | E5 | 659.255 | 10.278 | 3.132 | 0.184 | 0.178 | First-pass station; cut undersize and tune after bisque.
SCF-C5-01 | C5 | 3 | 5 | F5 | 698.456 | 9.701 | 3.709 | 0.195 | 0.188 | First-pass station; cut undersize and tune after bisque.
SCF-C5-01 | C5 | 4 | 7 | G5 | 783.991 | 8.643 | 4.768 | 0.205 | 0.198 | First-pass station; cut undersize and tune after bisque.
SCF-C5-01 | C5 | 5 | 9 | A5 | 880 | 7.7 | 5.711 | 0.22 | 0.213 | First-pass station; cut undersize and tune after bisque.
SCF-C5-01 | C5 | 6 | 11 | B5 | 987.767 | 6.86 | 6.551 | 0.236 | 0.227 | First-pass station; cut undersize and tune after bisque.

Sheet: DoE Matrix
run_id | phase | instrument_id | clay_body | wall_target | bore_profile | embouchure_geometry | mold_orientation | replicate | primary_response | decision_rule
SCF-R1-01 | Round 1 screening | SCF-D4-01 | Cone 6 stoneware | thin drain | cylindrical | round/standard oval | horizontal drain | screening | X/Y/Z shrink, playable response, cents error | Keep if no cracks, first octave speaks, median cents abs <= 35 after bisque tune.
SCF-R1-02 | Round 1 screening | SCF-D4-01 | Cone 6 stoneware | nominal drain | mild taper | long oval | vertical drain | screening | X/Y/Z shrink, playable response, cents error | Keep if no cracks, first octave speaks, median cents abs <= 35 after bisque tune.
SCF-R1-03 | Round 1 screening | SCF-D4-01 | Cone 6 stoneware | thick drain | cylindrical | round/standard oval | horizontal drain | screening | X/Y/Z shrink, playable response, cents error | Keep if no cracks, first octave speaks, median cents abs <= 35 after bisque tune.
SCF-R1-04 | Round 1 screening | SCF-D4-01 | Cone 6 porcelain | thin drain | mild taper | round/standard oval | vertical drain | screening | X/Y/Z shrink, playable response, cents error | Keep if no cracks, first octave speaks, median cents abs <= 35 after bisque tune.
SCF-R1-05 | Round 1 screening | SCF-D4-01 | Cone 6 porcelain | nominal drain | cylindrical | long oval | horizontal drain | screening | X/Y/Z shrink, playable response, cents error | Keep if no cracks, first octave speaks, median cents abs <= 35 after bisque tune.
SCF-R1-06 | Round 1 screening | SCF-D4-01 | Cone 6 porcelain | thick drain | mild taper | round/standard oval | vertical drain | screening | X/Y/Z shrink, playable response, cents error | Keep if no cracks, first octave speaks, median cents abs <= 35 after bisque tune.
SCF-R1-07 | Round 1 screening | SCF-G4-01 | Cone 6 stoneware | thin drain | mild taper | long oval | horizontal drain | screening | X/Y/Z shrink, playable response, cents error | Keep if no cracks, first octave speaks, median cents abs <= 35 after bisque tune.
SCF-R1-08 | Round 1 screening | SCF-G4-01 | Cone 6 stoneware | nominal drain | cylindrical | round/standard oval | vertical drain | screening | X/Y/Z shrink, playable response, cents error | Keep if no cracks, first octave speaks, median cents abs <= 35 after bisque tune.
SCF-R1-09 | Round 1 screening | SCF-G4-01 | Cone 6 stoneware | thick drain | mild taper | long oval | horizontal drain | screening | X/Y/Z shrink, playable response, cents error | Keep if no cracks, first octave speaks, median cents abs <= 35 after bisque tune.
SCF-R1-10 | Round 1 screening | SCF-G4-01 | Cone 6 porcelain | thin drain | cylindrical | long oval | vertical drain | screening | X/Y/Z shrink, playable response, cents error | Keep if no cracks, first octave speaks, median cents abs <= 35 after bisque tune.
SCF-R1-11 | Round 1 screening | SCF-G4-01 | Cone 6 porcelain | nominal drain | mild taper | round/standard oval | horizontal drain | screening | X/Y/Z shrink, playable response, cents error | Keep if no cracks, first octave speaks, median cents abs <= 35 after bisque tune.
SCF-R1-12 | Round 1 screening | SCF-G4-01 | Cone 6 porcelain | thick drain | cylindrical | long oval | vertical drain | screening | X/Y/Z shrink, playable response, cents error | Keep if no cracks, first octave speaks, median cents abs <= 35 after bisque tune.
SCF-R1-13 | Round 1 screening | SCF-C5-01 | Cone 6 stoneware | thin drain | cylindrical | round/standard oval | horizontal drain | screening | X/Y/Z shrink, playable response, cents error | Keep if no cracks, first octave speaks, median cents abs <= 35 after bisque tune.
SCF-R1-14 | Round 1 screening | SCF-C5-01 | Cone 6 stoneware | nominal drain | mild taper | long oval | vertical drain | screening | X/Y/Z shrink, playable response, cents error | Keep if no cracks, first octave speaks, median cents abs <= 35 after bisque tune.
SCF-R1-15 | Round 1 screening | SCF-C5-01 | Cone 6 stoneware | thick drain | cylindrical | round/standard oval | horizontal drain | screening | X/Y/Z shrink, playable response, cents error | Keep if no cracks, first octave speaks, median cents abs <= 35 after bisque tune.
SCF-R1-16 | Round 1 screening | SCF-C5-01 | Cone 6 porcelain | thin drain | mild taper | round/standard oval | vertical drain | screening | X/Y/Z shrink, playable response, cents error | Keep if no cracks, first octave speaks, median cents abs <= 35 after bisque tune.
SCF-R1-17 | Round 1 screening | SCF-C5-01 | Cone 6 porcelain | nominal drain | cylindrical | long oval | horizontal drain | screening | X/Y/Z shrink, playable response, cents error | Keep if no cracks, first octave speaks, median cents abs <= 35 after bisque tune.
SCF-R1-18 | Round 1 screening | SCF-C5-01 | Cone 6 porcelain | thick drain | mild taper | round/standard oval | vertical drain | screening | X/Y/Z shrink, playable response, cents error | Keep if no cracks, first octave speaks, median cents abs <= 35 after bisque tune.
SCF-R1-FAM-F4 | Round 1 family check | SCF-F4-01 | Best available from early screening | nominal drain | winner or cylindrical fallback | winner or standard oval fallback | winner or horizontal drain fallback | family fill-in | Interpolation across family range | Use to test whether shrink model interpolates between D4/G4/C5.
SCF-R1-FAM-A4 | Round 1 family check | SCF-A4-01 | Best available from early screening | nominal drain | winner or cylindrical fallback | winner or standard oval fallback | winner or horizontal drain fallback | family fill-in | Interpolation across family range | Use to test whether shrink model interpolates between G4/C5.

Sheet: Measurements
build_id | instrument_id | material_batch | mold_id | axis | feature | master_target_in | master_measured_in | wet_green_measured_in | bone_dry_measured_in | bisque_measured_in | glaze_measured_in | observed_total_shrink | round2_scale_multiplier | target_frequency_hz | measured_frequency_hz | cents_error | notes
SCF-R1-01-A | SCF-D4-01 |  |  | X | overall_length |  |  |  |  |  |  |  |  |  |  |  | Duplicate rows for each feature/axis/note.

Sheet: Shrink Fit
axis | initial_assumed_shrink | measured_mean_shrink | measured_std_dev | recommended_round2_shrink | apply_to_features | notes
X length | 0.12 |  |  |  | overall length, hole station X, embouchure station X | Separate D4/G4/C5 if shrink depends on length or mold orientation.
Y width | 0.12 |  |  |  | bore ID Y, OD Y, horizontal hole/embouchure dimensions | Use bore rings to separate shrink from wall buildup.
Z height | 0.12 |  |  |  | OD Z, wall thickness, vertical hole/embouchure dimensions | Watch sag/ovalization separately from true shrink.

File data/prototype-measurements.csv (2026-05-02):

build_id | instrument_id | material_batch | mold_id | axis | feature | master_target_in | master_measured_in | wet_green_measured_in | bone_dry_measured_in | bisque_measured_in | glaze_measured_in | observed_total_shrink | round2_scale_multiplier | target_frequency_hz | measured_frequency_hz | cents_error | notes
SCF-R1-01-A | SCF-D4-01 |  |  | X | overall_length |  |  |  |  |  |  | =IF(OR(H2="",L2=""),"",1-L2/H2) | =IF(OR(G2="",L2=""),"",G2/L2) |  |  | =IF(OR(O2="",P2=""),"",1200*LOG(P2/O2,2)) | Duplicate rows for each feature/axis/note.

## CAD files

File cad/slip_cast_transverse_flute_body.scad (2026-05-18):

// Slip-cast transverse flute body concept model.
// Units: inches. Convert to mm in slicer/CAD if needed.
// This is a geometry starter, not a final mold with draft analysis.
// Dimensions are first-pass prototype targets from family-spec.csv and
// data/fired-dimension-targets.csv; they are not measured tuning proof.

instrument_id = "SCF-G4-01";
family_spec_source = "family-spec.csv";
design_table_source = "data/fired-dimension-targets.csv";
fired_length = 18.388;
fired_bore = 0.669;
fired_wall = 0.130;
shrink_x = 0.12;
shrink_y = 0.12;
shrink_z = 0.12;

master_length = fired_length / (1 - shrink_x);
master_bore_y = fired_bore / (1 - shrink_y);
master_bore_z = fired_bore / (1 - shrink_z);
master_od_y = (fired_bore + 2*fired_wall) / (1 - shrink_y);
master_od_z = (fired_bore + 2*fired_wall) / (1 - shrink_z);

inch = 25.4;

module flute_outer() {
  scale([1, master_od_y/master_od_z, 1])
    rotate([0,90,0])
      cylinder(h=master_length*inch, d=master_od_z*inch, $fn=96);
}

module flute_bore() {
  scale([1, master_bore_y/master_bore_z, 1])
    translate([-0.01*inch,0,0])
      rotate([0,90,0])
        cylinder(h=(master_length+0.02)*inch, d=master_bore_z*inch, $fn=96);
}

difference() {
  flute_outer();
  flute_bore();
}

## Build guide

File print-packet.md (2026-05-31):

# Slip-Cast Transverse Flute Family Print Packet

Generated: 2026-05-02
Packet folder: `/mnt/c/Users/Tony/Documents/GitHub/transverse-flute`

## File Map

| File | Purpose |
| --- | --- |
| `design.md` | Project intent, catalog metadata, assumptions, and validation plan. |
| `bom.csv` | Starter bill of materials with part categories, quantities, drawing refs, and notes. |
| `sourcing.csv` | Supplier/search tracker with specs, price/date fields, lead time, substitutes, and risks. |
| `cut-list.csv` | Rough/final stock sizes, material, grain/orientation, operations, yield, and offcuts. |
| `drawing-brief.md` | Manufacturing drawing and technical product sketch brief. |
| `assembly-manual.md` | Shop-facing sequence, tools, fixtures, safety, tuning, finishing, and maintenance notes. |
| `validation.csv` | Target/measured values, tolerance, environment, result, and tuning/build action log. |
| `supplier-rfq.md` | Supplier email/request-for-quote starter. |
| `visual-bom-brief.md` | Art direction for an image-forward visual BOM. |
| `transverse-flute-starter.wl` | Wolfram starter for physics, optimization, visualization, and validation. |
| `README.md` | Project artifact. |
| `doe-plan.md` | Project artifact. |
| `mold-workflow.md` | Project artifact. |

## design.md

Project intent, catalog metadata, assumptions, and validation plan.

# Slip-Cast Transverse Flute Family Build Packet

## Source And Scope

- Date: `2026-05-02`
- Source workbook inspected: `/mnt/c/Users/Tony/Documents/Claude/Projects/Career/flutes-staging/Flutes-AI.xlsx`
- Relevant sheet: `Irish Flute`, which uses open-open flute math, D4 sanity dimensions, end correction, and 6-hole diatonic placement.
- Ceramic workflow references inspected: `Ocarina`, `Udu Drum Family`, and `vessel-flute-lab` build packets.

This packet is for unkeyed transverse ceramic flute prototypes made by slip casting. The acoustic dimensions below are final fired targets. Master and mold dimensions are scaled from those targets using provisional X/Y/Z shrink factors.

## Design Intent

Build a family across D4, F4, G4, A4, and C5 so the study sees both long-body casting behavior and smaller higher-key behavior. Round 1 is not trying to prove a finished product. It is meant to produce a clean data set:

- actual X/Y/Z fired shrink by material, wall, and mold orientation,
- actual bore roundness and wall buildup,
- pitch and response error against the open-open first-pass model,
- embouchure and bore-profile preferences before Round 2.

## Governing Model

First-pass open-open transverse flute model:

```text
f = c / (2 * L_eff)
L_acoustic = c / (2 * f)
end_correction_total ~= 0.6 * bore_ID
sounding_length ~= L_acoustic - end_correction_total
hole_distance_from_foot ~= L_acoustic * (fundamental_frequency / hole_frequency)
```

The hole positions are first-pass acoustic stations. Ceramic wall thickness, hole chimney height, undercutting, bore ovalization, embouchure geometry, and stopper position will move real pitch. The packet therefore makes hole cuts undersize and expects bisque-stage tuning.

## Initial Family Targets

| ID | Key | Bore ID | OD | Sounding length | Pre-trim fired length | Master X length @12% |
| --- | --- | ---: | ---: | ---: | ---: | ---: |
| SCF-D4-01 | D4 | 0.748 in | 1.028 in | 22.625 in | 24.247 in | 27.554 in |
| SCF-F4-01 | F4 | 0.669 in | 0.939 in | 19.001 in | 20.505 in | 23.301 in |
| SCF-G4-01 | G4 | 0.669 in | 0.929 in | 16.885 in | 18.388 in | 20.895 in |
| SCF-A4-01 | A4 | 0.591 in | 0.841 in | 15.045 in | 16.432 in | 18.673 in |
| SCF-C5-01 | C5 | 0.512 in | 0.742 in | 12.643 in | 13.911 in | 15.808 in |

## Shrinkage Model

Coordinate convention:

- X = flute length/bore axis/hole stations.
- Y = side-to-side bore and outside width.
- Z = vertical height, wall buildup, and ovalization direction.

```text
master_x = fired_target_x / (1 - shrink_x)
master_y = fired_target_y / (1 - shrink_y)
master_z = fired_target_z / (1 - shrink_z)
observed_shrink_axis = 1 - fired_measured_axis / master_measured_axis
round2_master_axis = round1_master_axis * fired_target_axis / fired_measured_axis
```

Initial assumption is `shrink_x = shrink_y = shrink_z = 0.12`. This is a placeholder, not a material claim.

## Round 1 Success Criteria

- No full-length cracking through drying, bisque, or glaze fire.
- Bore remains measurable and cleanable.
- Embouchure speaks a stable fundamental and octave on at least the G4 or C5 prototypes.
- Hole tuning can be brought within +/-35 cents after bisque without grotesque hole enlargement.
- X/Y/Z shrink measurements have enough consistency to choose Round 2 scale factors.

## Round 2 Decision Path

1. Fit shrink_x, shrink_y, and shrink_z from bars, bore rings, and flute features.
2. Choose the best material/profile/embouchure combination from the DoE.
3. Update the workbook inputs and regenerate master dimensions.
4. Rebuild the full five-key family using corrected X/Y/Z scale factors.
5. Tighten acceptance to +/-10 cents for tuned notes and +/-0.010 to +/-0.030 in on critical fired dimensions.

## Open Assumptions

- Bore diameters are adapted from the existing Irish/simple-system flute design range, then made ceramic-friendly with thinner walls than wood.
- A removable head stopper or cork test plug is assumed for Round 1 because it gives a reversible tuning variable.
- All prices, supplier availability, and exact clay data must be date-checked before buying.
- CAD mold release and split lines need confirmation in the actual CAD model before cutting production molds.

## bom.csv

Starter bill of materials with part categories, quantities, drawing refs, and notes.

| item_id | subsystem | item | qty | unit | material_spec | make_buy | drawing_ref | notes |
| --- | --- | --- | --- | --- | --- | --- | --- | --- |
| SCF-BOM-001 | CAD/master | Parametric flute body master set | 5 | masters | Sealed 3D print or machined master, scaled by X/Y/Z shrink factors | Make | drawings/SCF-*-body.svg; cad/slip_cast_transverse_flute_body.scad | Use as mold masters or CAD reference. Add mold split before production tooling. |
| SCF-BOM-002 | Mold | Two-piece or three-piece plaster molds | 5+ | molds | Pottery plaster, registration keys, pour/drain reservoir | Make | drawings/mold-stack.svg | D4 may need sectional mold or reinforced cradle due to length. |
| SCF-BOM-003 | Material | Cone 6 stoneware casting slip | TBD | gallons | Casting slip with known fired shrinkage and absorption | Buy/mix | data/doe-build-matrix.csv | Date-check supplier and record batch number. |
| SCF-BOM-004 | Material | Cone 6 porcelain casting slip | TBD | gallons | Porcelain slip for comparison runs | Buy/mix | data/doe-build-matrix.csv | Higher shrink/warpage risk, better density and surface. |
| SCF-BOM-005 | Tuning | Diamond needle files and small diamond burrs | 1 | set | Fine files for bisque and fired ceramic hole tuning | Buy | assembly-manual.md | Avoid glazing acoustic edges after tuning. |
| SCF-BOM-006 | Validation | Measurement kit | 1 | kit | Calipers, bore gauges/pin gauges, tuner, mic, thermometer/hygrometer, scale | Use/buy | validation.csv | Use the same tuner/mic distance for all response tests. |
| SCF-BOM-007 | Voicing | Cork/stopper test kit | 5 | sets | Cork, silicone, or printed plug for head-end tuning experiments | Make/buy | drawing-brief.md | Treat head-stopper position as an adjustable variable before ceramic-integral solutions. |
| SCF-BOM-008 | Finish | Wax resist and glaze test set | 1 | set | Food-safe/contact-safe glaze where mouth contact occurs; acoustic edges waxed clear | Buy | mold-workflow.md | Keep glaze out of embouchure, bore, tone holes, and stopper fit surfaces. |

## sourcing.csv

Supplier/search tracker with specs, price/date fields, lead time, substitutes, and risks.

| source_id | category | spec | supplier_or_search_terms | qty | date_checked | unit_price | lead_time | substitution_rule | risk_notes |
| --- | --- | --- | --- | --- | --- | --- | --- | --- | --- |
| SRC-SLIP-STONEWARE | Ceramic slip | Cone 6 stoneware casting slip, published shrinkage and absorption data | local ceramic supplier cone 6 stoneware casting slip shrinkage data sheet | TBD |  |  |  | Must have measured or published shrinkage; color can vary. | Live price and availability intentionally blank until purchase planning. |
| SRC-SLIP-PORCELAIN | Ceramic slip | Cone 6 porcelain casting slip, low warpage preferred | cone 6 porcelain casting slip shrinkage casting data sheet | TBD |  |  |  | Substitute only with data-backed shrink and firing schedule. | Porcelain may move more; use bars and rings before long D4 molds. |
| SRC-PLASTER | Mold material | Pottery plaster or high-strength mold plaster | USG pottery plaster No. 1 local ceramic supplier | TBD |  |  |  | Must be absorbent mold plaster, not general patching plaster. | Mold drying time affects casting wall thickness and repeatability. |
| SRC-PRINT | Master fabrication | High-resolution sealed print or machined master; smooth bore core strategy | SLA print service large format resin smooth finish or in-house FDM sealed master | 5 masters plus coupons |  |  |  | Any method is acceptable if master dimensions are measured and sealed. | Layer lines transfer to plaster and may disturb mold release. |
| SRC-TUNING | Tuning tools | Diamond needle files, small diamond burrs, tuner/mic | diamond needle file set ceramic tuning burr chromatic tuner measurement microphone | 1 kit |  |  |  | Prefer fine controlled abrasion over aggressive rotary cutting. | Over-opening holes is not reversible. |

## cut-list.csv

Rough/final stock sizes, material, grain/orientation, operations, yield, and offcuts.

| cut_id | part | qty | rough_dimensions | final_dimensions | material | orientation | operation | yield_or_notes |
| --- | --- | --- | --- | --- | --- | --- | --- | --- |
| CUT-SCF-D4-01 | Scaled master body blank/envelope | 1 | 28.55 x 1.67 x 1.67 in | 27.554 x 1.168 x 1.168 in | Sealed printed/machined master | X along bore axis; mark top/embouchure datum | Print/machine, sand, seal, measure, then mold | Add handles/sprues outside acoustic envelope only. |
| CUT-SCF-F4-01 | Scaled master body blank/envelope | 1 | 24.3 x 1.57 x 1.57 in | 23.301 x 1.067 x 1.067 in | Sealed printed/machined master | X along bore axis; mark top/embouchure datum | Print/machine, sand, seal, measure, then mold | Add handles/sprues outside acoustic envelope only. |
| CUT-SCF-G4-01 | Scaled master body blank/envelope | 1 | 21.9 x 1.56 x 1.56 in | 20.895 x 1.056 x 1.056 in | Sealed printed/machined master | X along bore axis; mark top/embouchure datum | Print/machine, sand, seal, measure, then mold | Add handles/sprues outside acoustic envelope only. |
| CUT-SCF-A4-01 | Scaled master body blank/envelope | 1 | 19.67 x 1.46 x 1.46 in | 18.673 x 0.956 x 0.956 in | Sealed printed/machined master | X along bore axis; mark top/embouchure datum | Print/machine, sand, seal, measure, then mold | Add handles/sprues outside acoustic envelope only. |
| CUT-SCF-C5-01 | Scaled master body blank/envelope | 1 | 16.81 x 1.34 x 1.34 in | 15.808 x 0.843 x 0.843 in | Sealed printed/machined master | X along bore axis; mark top/embouchure datum | Print/machine, sand, seal, measure, then mold | Add handles/sprues outside acoustic envelope only. |
| CUT-SHRINK-BAR-X | Shrinkage bar set | 12 | 6.5 x 0.5 x 0.25 in master or cast bars | Measure fired length, width, thickness | Each slip body | Label X, Y, Z and casting direction | Cast alongside every flute run | Primary anisotropic shrink data. |
| CUT-BORE-RING | Bore/roundness ring coupons | 12 | OD/ID matching each bore family | Measure fired ID/OD in Y and Z | Each slip body | Same drain orientation as flute | Cast with flute body | Detect ovalization and wall-thickness drift. |

## drawing-brief.md

Manufacturing drawing and technical product sketch brief.

# Drawing Brief

## Required Views

- Family overview showing D4, F4, G4, A4, and C5 fired target lengths.
- Individual body plan view for each key with X-axis datum, embouchure, tone holes, bore ID, OD, and fired/master length notes.
- Section view at embouchure showing wall thickness, bore, hole edge, undercut zone, and stopper relationship.
- Section view through a tone hole showing chimney height and allowed tuning/undercut area.
- Mold stack view showing split line, registration keys, pour/drain direction, seam cleanup zone, and optional three-piece D4 strategy.
- Shrink coupon drawing with X/Y/Z labels and measurement flats.

## Critical Dimensions

| Dimension | Source | Tolerance Intent |
| --- | --- | --- |
| Fired sounding length | `data/fired-dimension-targets.csv` and workbook | Tuning critical |
| Embouchure center from head | workbook, initial 1.5 x bore ID | Response and tuning |
| Bore ID Y/Z | workbook and bore ring measurement | Tuning, response, shrink fit |
| Tone-hole stations X | `data/hole-schedule.csv` | Tuning critical; first-pass only |
| Tone-hole diameters | `data/hole-schedule.csv` | Cut undersize; tune after bisque |
| Wall thickness | DoE wall target and measured coupons | Durability, weight, hole chimney |
| Master X/Y/Z scale | shrink model | Process critical |

## Existing Drawings

- `drawings/family-overview.svg`
- `drawings/mold-stack.svg`
- `drawings/SCF-D4-01-body.svg`
- `drawings/SCF-F4-01-body.svg`
- `drawings/SCF-G4-01-body.svg`
- `drawings/SCF-A4-01-body.svg`
- `drawings/SCF-C5-01-body.svg`

These are SVG shop-review drawings. They are not a substitute for final CAD mold drawings with draft and release analysis.

## assembly-manual.md

Shop-facing sequence, tools, fixtures, safety, tuning, finishing, and maintenance notes.

# Slip-Cast Transverse Flute Assembly Manual

## Tools

- CAD or OpenSCAD/SolidWorks for master geometry.
- 3D printer or machining route for sealed masters.
- Plaster mold supplies, cottle boards, scale, mixing bucket, release, clamps.
- Casting slip, deflocculant tools if mixing, and slip hydrometer if available.
- Needle tools, hole cutters, small round cutters, ribs, sponges, fettling knife.
- Calipers, bore gauges or pin gauges, scale, tuner, microphone, thermometer/hygrometer.
- Diamond needle files and fine diamond burrs.
- Wax resist, glaze, kiln access, and kiln-safe supports.

## Build Sequence

1. Pick a build row from `data/doe-build-matrix.csv`.
2. Confirm workbook shrink inputs and export the master dimensions for that run.
3. Print or machine the master, then sand, seal, and measure it.
4. Build the plaster mold with marked datums and registration keys.
5. Dry the mold completely enough for repeatable casting.
6. Pour slip, hold for the planned drain time, drain in the assigned orientation, and log the run.
7. Demold at leather hard and clean seams while preserving datums.
8. Cut embouchure and pilot tone holes undersize.
9. Dry slowly with support under the long body.
10. Bisque fire.
11. Measure X/Y/Z features, bore, mass, and first tuning.
12. Tune holes and embouchure in small steps using diamond tools.
13. Wax resist acoustic edges and glaze only after tuning is understood.
14. Final fire, then remeasure dimensions and tuning.
15. Enter data into `data/prototype-measurements.csv` and update `data/shrinkage-fit.csv`.

## Tuning Notes

- Enlarge an open tone hole to raise that note.
- Undercutting can raise pitch and improve response, but it changes the correction model.
- A head stopper gives a reversible global tuning lever; use it in Round 1 before committing to an integral ceramic head solution.
- Do not glaze the embouchure edge, tone-hole chimneys, bore interior, or stopper seating surface during the data rounds.

## Safety And Handling

- Fired ceramic edges and dust need care; use wet sanding or dust control.
- Long greenware bodies need full support while drying and moving.
- Label every prototype before it enters the kiln so the DoE data survives the shop day.

## validation.csv

Target/measured values, tolerance, environment, result, and tuning/build action log.

| build_id | instrument_id | stage | measurement | target_value | unit | tolerance | measured_value | environment | result | action |
| --- | --- | --- | --- | --- | --- | --- | --- | --- | --- | --- |
|  | SCF-D4-01 | final fired | fundamental | 293.665 | Hz | +/-10 cents after tuning; Round 1 accepts +/-35 cents before correction |  | Record temp F / humidity / tuner distance |  | Move stopper, file embouchure/tone holes, or update Round 2 CAD factor. |
|  | SCF-D4-01 | final fired | overall length X | 24.247 | in | +/-0.030 in before trim |  | Room temp; calipers/tape ID |  | Use target/measured as Round 2 X scale correction. |
|  | SCF-D4-01 | final fired | bore ID Y/Z | 0.748 | in | +/-0.010 in; record Y and Z separately |  | Pin gauge or bore gauge |  | Use Y/Z shrink correction and check ovalization. |
|  | SCF-F4-01 | final fired | fundamental | 349.228 | Hz | +/-10 cents after tuning; Round 1 accepts +/-35 cents before correction |  | Record temp F / humidity / tuner distance |  | Move stopper, file embouchure/tone holes, or update Round 2 CAD factor. |
|  | SCF-F4-01 | final fired | overall length X | 20.505 | in | +/-0.030 in before trim |  | Room temp; calipers/tape ID |  | Use target/measured as Round 2 X scale correction. |
|  | SCF-F4-01 | final fired | bore ID Y/Z | 0.669 | in | +/-0.010 in; record Y and Z separately |  | Pin gauge or bore gauge |  | Use Y/Z shrink correction and check ovalization. |
|  | SCF-G4-01 | final fired | fundamental | 391.995 | Hz | +/-10 cents after tuning; Round 1 accepts +/-35 cents before correction |  | Record temp F / humidity / tuner distance |  | Move stopper, file embouchure/tone holes, or update Round 2 CAD factor. |
|  | SCF-G4-01 | final fired | overall length X | 18.388 | in | +/-0.030 in before trim |  | Room temp; calipers/tape ID |  | Use target/measured as Round 2 X scale correction. |
|  | SCF-G4-01 | final fired | bore ID Y/Z | 0.669 | in | +/-0.010 in; record Y and Z separately |  | Pin gauge or bore gauge |  | Use Y/Z shrink correction and check ovalization. |
|  | SCF-A4-01 | final fired | fundamental | 440.0 | Hz | +/-10 cents after tuning; Round 1 accepts +/-35 cents before correction |  | Record temp F / humidity / tuner distance |  | Move stopper, file embouchure/tone holes, or update Round 2 CAD factor. |
|  | SCF-A4-01 | final fired | overall length X | 16.432 | in | +/-0.030 in before trim |  | Room temp; calipers/tape ID |  | Use target/measured as Round 2 X scale correction. |
|  | SCF-A4-01 | final fired | bore ID Y/Z | 0.591 | in | +/-0.010 in; record Y and Z separately |  | Pin gauge or bore gauge |  | Use Y/Z shrink correction and check ovalization. |
|  | SCF-C5-01 | final fired | fundamental | 523.251 | Hz | +/-10 cents after tuning; Round 1 accepts +/-35 cents before correction |  | Record temp F / humidity / tuner distance |  | Move stopper, file embouchure/tone holes, or update Round 2 CAD factor. |
|  | SCF-C5-01 | final fired | overall length X | 13.911 | in | +/-0.030 in before trim |  | Room temp; calipers/tape ID |  | Use target/measured as Round 2 X scale correction. |
|  | SCF-C5-01 | final fired | bore ID Y/Z | 0.512 | in | +/-0.010 in; record Y and Z separately |  | Pin gauge or bore gauge |  | Use Y/Z shrink correction and check ovalization. |

## supplier-rfq.md

Supplier email/request-for-quote starter.

# Supplier RFQ Starter

Subject: RFQ - slip-cast ceramic flute prototype materials and master/mold support

Hello,

I am prototyping a family of slip-cast ceramic transverse flutes and need materials or fabrication support with measured shrinkage and repeatability data.

Please quote the following where available:

- Cone 6 stoneware casting slip with shrinkage, absorption, and firing schedule data.
- Cone 6 porcelain casting slip with shrinkage, absorption, and firing schedule data.
- Pottery plaster suitable for slip-casting molds.
- Optional high-resolution master printing or machining for long cylindrical flute masters up to about 29 in master length.

Please include:

- unit price and minimum order,
- current availability and lead time,
- shipping or local pickup options,
- technical data sheets,
- recommended mold/drying/firing notes,
- any substitutions you recommend for thin-walled musical instrument bodies.

The prototypes will be measured for X/Y/Z shrinkage, bore roundness, wall thickness, and acoustic tuning after firing.

Thank you,

Tony

## visual-bom-brief.md

Art direction for an image-forward visual BOM.

# Visual BOM Brief

Create an image-forward BOM plate in Tony's Ashiko BOM style:

- Header: Slip-Cast Transverse Flute Family, quote date, material status, and Round 1 / Round 2 label.
- Hero image: family fan of the five fired target flutes or a clean CAD render.
- Table rows grouped by CAD/master, mold, ceramic material, tuning tools, validation tools, and finishing.
- Include thumbnails for: master, plaster mold halves, casting slip, shrink bars, bore rings, diamond files, tuner/mic, cork/stopper kit.
- Add callouts showing X/Y/Z shrink axes and where measurements are taken.
- Mark generated/CAD imagery as placeholders until replaced with shop photos or supplier images.

Important: the visual BOM should communicate process and parts, not invent unverified dimensions. Pull all numbers from the workbook and CSVs.

## transverse-flute-starter.wl

Wolfram starter for physics, optimization, visualization, and validation.

```wolfram
(* Slip-Cast Transverse Flute Family - Wolfram starter *)

a4 = 440;
cIn = 13552;
freq[midi_] := a4*2^((midi - 69)/12);
acousticLength[f_] := cIn/(2*f);
endCorrection[bore_] := 0.6*bore;
soundingLength[midi_, bore_] := acousticLength[freq[midi]] - endCorrection[bore];
holeDistanceFromFoot[midiFund_, interval_, bore_] :=
  acousticLength[freq[midiFund]] * freq[midiFund]/freq[midiFund + interval];
centsError[measured_, target_] := 1200*Log2[measured/target];
masterDim[fired_, shrink_] := fired/(1 - shrink);
observedShrink[master_, fired_] := 1 - fired/master;

family = {
  <|"ID" -> "SCF-D4-01", "MIDI" -> 62, "Bore" -> .748|>,
  <|"ID" -> "SCF-F4-01", "MIDI" -> 65, "Bore" -> .669|>,
  <|"ID" -> "SCF-G4-01", "MIDI" -> 67, "Bore" -> .669|>,
  <|"ID" -> "SCF-A4-01", "MIDI" -> 69, "Bore" -> .591|>,
  <|"ID" -> "SCF-C5-01", "MIDI" -> 72, "Bore" -> .512|>
};

Dataset[
  family /. inst_Association :> Join[
    inst,
    <|
      "FreqHz" -> freq[inst["MIDI"]],
      "SoundingLengthIn" -> soundingLength[inst["MIDI"], inst["Bore"]],
      "MasterXAt12PctIn" -> masterDim[soundingLength[inst["MIDI"], inst["Bore"]], .12]
    |>
  ]
]

Manipulate[
 Plot[
  Evaluate@Table[Sin[n*Pi*x/soundingLength[midi, bore]], {n, 1, 3}],
  {x, 0, soundingLength[midi, bore]},
  PlotRange -> {-1, 1},
  PlotLabel -> Row[{"Standing wave sketch, MIDI ", midi, ", bore ", bore, " in"}]
 ],
 {{midi, 62}, 62, 72, 1},
 {{bore, .748}, .45, .85, .001}
]
```

## README.md

Project artifact.

# Transverse Flute - Experimental Slip-Cast Ceramic Flute Lab

> *A preparatory design repository for a family of slip-cast ceramic transverse flutes - unvalidated, intentionally provisional, and ready to become the project accelerator once materials and shop time arrive.*

Family overview drawing
*First-pass fired target family for D4, F4, G4, A4, and C5. These are planning dimensions, not proven instrument dimensions.*

## What this is

Engineering documentation for an **experimental slip-cast ceramic transverse flute family**. The idea is to start with target final fired dimensions, scale the build masters for X/Y/Z ceramic shrinkage, cast and fire the first round, measure what actually happened, then use those measurements to correct the second round.

This repository is not a finished portfolio of validated instruments yet. It is creative preparatory space: an accelerator, launchpad, laboratory notebook, design-control folder, and build packet so the project can move fast once supplies are acquired.

The repository combines:

1. **A parametric design workbook** ([`Slip-Cast-Transverse-Flute-Family.xlsx`](Slip-Cast-Transverse-Flute-Family.xlsx)) with fired target dimensions, provisional master scaling, tone-hole schedules, a DoE matrix, measurement tables, and shrink-factor fitting sheets.
2. **A Round 1 design-of-experiments plan** ([`doe-plan.md`](doe-plan.md)) for comparing clay bodies, wall targets, bore profiles, embouchure geometry, and mold/drain orientation.
3. **Shop-facing build documentation**: [`design.md`](design.md), [`mold-workflow.md`](mold-workflow.md), [`assembly-manual.md`](assembly-manual.md), [`validation.csv`](validation.csv), [`bom.csv`](bom.csv), [`sourcing.csv`](sourcing.csv), and [`supplier-rfq.md`](supplier-rfq.md).
4. **Drawings and starter CAD** in [`drawings/`](drawings/), [`cad/`](cad/), and [`cnc/`](cnc/) so the first physical work can move from sketch to master/mold planning without starting from a blank page.

Sister project to [`flutes`](https://github.com/tonykoop/flutes), [`fujara`](https://github.com/tonykoop/fujara), [`didgeridoo`](https://github.com/tonykoop/didgeridoo), [`tongue-drum`](https://github.com/tonykoop/tongue-drum), and the broader instrument workshop documentation in this GitHub folder.

## Status and validation warning

This design has **not been physically built, tuned, fired, or validated**. The dimensions are first-pass engineering targets based on open-open flute math, ceramic shrinkage assumptions, and Tony's existing flute design-table habits.

Use every number in this repository as one of:

- `target` - what the fired instrument is intended to become,
- `assumption` - what Round 1 is testing,
- `starting point` - what will be corrected after measurement.

The design is ready for preparation, quoting, sourcing, CAD cleanup, mold planning, and experimental setup. It is not ready to be treated as a proven flute recipe.

## Background - why slip casting changes the flute problem

A transverse flute is an open-open air column excited by a player blowing across an embouchure edge. In a wooden or metal flute, the maker can usually machine the bore and holes directly to final dimensions, then tune by controlled cutting, undercutting, or keywork adjustments.

Slip-cast ceramic adds a different engineering loop:

- the model/master is not the final size,
- wet clay, bone-dry clay, bisque, and glaze-fired ceramic each move differently,
- X/Y/Z shrinkage may not be equal,
- long thin tubes can sag or ovalize,
- wall buildup changes tone-hole chimney height,
- glaze can damage acoustic edges if it enters the embouchure, bore, or holes.

That makes this project a natural fit for a measured iteration cycle. Round 1 is mostly about learning the clay/process correction factors. Round 2 is where the design becomes more serious.

## Governing acoustic model

First-pass model:

```text
f = c / (2 * L_eff)
L_acoustic = c / (2 * f)
end_correction_total ~= 0.6 * bore_ID
sounding_length ~= L_acoustic - end_correction_total
hole_distance_from_foot ~= L_acoustic * (fundamental_frequency / hole_frequency)
```

This is enough to create a rational starting family, not enough to declare success. Embouchure shape, hole chimney height, wall thickness, bore roundness, stopper position, undercutting, and ceramic surface quality will all move the real instrument.

## The first design family

| ID | Key | Role | Fired pre-trim length | Initial master X @ 12% shrink |
| --- | --- | --- | ---: | ---: |
| SCF-D4-01 | D4 | Low reference / long-body risk case | 24.247 in | 27.554 in |
| SCF-F4-01 | F4 | Family interpolation check | 20.505 in | 23.301 in |
| SCF-G4-01 | G4 | Middle reference / likely first practical prototype | 18.388 in | 20.895 in |
| SCF-A4-01 | A4 | Family interpolation check | 16.432 in | 18.673 in |
| SCF-C5-01 | C5 | Soprano / short-body response check | 13.911 in | 15.808 in |

The detailed target table is in [`data/fired-dimension-targets.csv`](data/fired-dimension-targets.csv). The first-pass hole schedule is in [`data/hole-schedule.csv`](data/hole-schedule.csv).

## Shrinkage model

Coordinate convention:

- X = flute length, bore axis, embouchure station, and tone-hole stations.
- Y = side-to-side bore/OD width and horizontal hole dimensions.
- Z = vertical bore/OD height, wall buildup direction, sag, and ovalization.

The workbook starts at a deliberately provisional 12% shrink in each axis:

```text
master_x = fired_target_x / (1 - shrink_x)
master_y = fired_target_y / (1 - shrink_y)
master_z = fired_target_z / (1 - shrink_z)
observed_shrink_axis = 1 - fired_measured_axis / master_measured_axis
round2_master_axis = round1_master_axis * fired_target_axis / fired_measured_axis
```

Those values are placeholders until fired test bars, bore rings, and flute bodies are measured.

## Round 1 DoE

Round 1 is a screening study, not a production batch. It varies:

- key/scale: D4, G4, and C5 screening with F4/A4 family fill-ins,
- clay body: cone 6 stoneware and cone 6 porcelain,
- wall target: thin, nominal, and thick drain conditions,
- bore profile: cylindrical and mild taper,
- embouchure geometry: standard oval and longer oval,
- mold/drain orientation: horizontal and vertical.

Primary responses:

- X/Y/Z shrink,
- bore roundness and wall thickness,
- crack/warp/sag/seam outcomes,
- fundamental and scale-note cents error,
- octave response and breath threshold,
- subjective playability and tonal stability.

The run matrix is in [`data/doe-build-matrix.csv`](data/doe-build-matrix.csv).

## Engineering challenges this repository is meant to capture

**1. Translating additive-manufacturing shrink intuition into ceramic slip casting.** The project deliberately separates target fired dimensions from master dimensions, then treats X/Y/Z shrink as measured process data rather than a fixed catalog value.

**2. Keeping the acoustic model honest.** Open-open flute math gives the starting geometry, but ceramic flute behavior will be corrected from measured prototypes. The validation sheets are as important as the design table.

**3. Designing for a fragile long body before the materials are on hand.** The D4 body is long enough that mold strategy, drying support, seam cleanup, and bore ovalization are major design concerns before a single note is played.

**4. Creating a repository that becomes useful the moment supplies arrive.** This repo is the setup work: BOM, sourcing, RFQ, shop sequence, drawings, CAD starter, DoE protocol, and measurement schema.

## How to use this repository

Start here:

- [`print-packet.html`](print-packet.html) - browser-friendly combined packet for reading or printing.
- [`Slip-Cast-Transverse-Flute-Family.xlsx`](Slip-Cast-Transverse-Flute-Family.xlsx) - the parametric workbook and measurement hub.
- [`design.md`](design.md) - the compact engineering brief.
- [`doe-plan.md`](doe-plan.md) - the experimental plan.
- [`mold-workflow.md`](mold-workflow.md) - the slip-casting control plan.
- [`assembly-manual.md`](assembly-manual.md) - shop sequence from master through final validation.

Then, once supplies are acquired:

1. Date-check suppliers and update [`sourcing.csv`](sourcing.csv).
2. Pick the first Round 1 run from [`data/doe-build-matrix.csv`](data/doe-build-matrix.csv).
3. Make and measure the master.
4. Cast shrink bars, bore rings, and the flute body together.
5. Record measurements in [`data/prototype-measurements.csv`](data/prototype-measurements.csv).
6. Fit Round 2 corrections in [`data/shrinkage-fit.csv`](data/shrinkage-fit.csv).

## Repository structure

```text
transverse-flute/
|-- README.md
|-- LICENSE                    <- CC-BY 4.0
|-- Slip-Cast-Transverse-Flute-Family.xlsx
|-- design.md
|-- doe-plan.md
|-- mold-workflow.md
|-- assembly-manual.md
|-- bom.csv
|-- sourcing.csv
|-- supplier-rfq.md
|-- validation.csv
|-- cut-list.csv
|-- print-packet.md / print-packet.html
|-- capstone-deck.md
|-- data/
|   |-- fired-dimension-targets.csv
|   |-- hole-schedule.csv
|   |-- doe-build-matrix.csv
|   |-- prototype-measurements.csv
|   `-- shrinkage-fit.csv
|-- drawings/
|   |-- family-overview.svg
|   |-- mold-stack.svg
|   `-- SCF-*-body.svg
|-- cad/
|   `-- slip_cast_transverse_flute_body.scad
|-- cnc/
|   `-- master-fabrication-plan.md
`-- scripts/
    `-- generate_packet.py
```

## Status

| Section | Status |
| --- | --- |
| Repo description and CC-BY license | done |
| Parametric workbook | first-pass generated |
| Fired target dimension table | first-pass generated |
| Tone-hole schedule | first-pass generated |
| Round 1 DoE plan | drafted |
| Mold workflow | drafted |
| Shop assembly manual | drafted |
| CAD body starter | preliminary OpenSCAD concept |
| Manufacturing drawings | SVG review drawings only |
| Supplier pricing and availability | not checked |
| Physical prototypes | not started |
| Fired shrink validation | no data yet |
| Acoustic validation | no data yet |
| Round 2 correction factors | pending Round 1 |

## License

Released under [CC-BY 4.0](LICENSE) - use freely with attribution. The written documentation, generated design tables, drawings, scripts, and experimental framework in this repository are my own preparatory engineering work. Because the instrument design is unvalidated, reuse should preserve the experimental status and measurement assumptions until physical builds prove otherwise.

## doe-plan.md

Project artifact.

# Round 1 DoE Plan

## Purpose

Round 1 is a screening study for a slip-cast transverse flute family. It should answer:

- What are the actual X/Y/Z shrink factors for each clay/process condition?
- Which clay body and wall target survive long flute geometry?
- Does a cylindrical bore or mild taper give better response after ceramic firing?
- Which embouchure geometry speaks cleanly before excessive hand correction?
- Do shrink and acoustic errors interpolate across D4, G4, and C5 well enough to build F4 and A4 in Round 2?

## Factors

| Factor | Levels |
| --- | --- |
| Key/scale | D4, G4, C5 screening; F4 and A4 family fill-ins |
| Clay body | Cone 6 stoneware, Cone 6 porcelain |
| Wall target | thin drain, nominal drain, thick drain |
| Bore profile | cylindrical, mild taper |
| Embouchure | standard oval, longer oval |
| Mold orientation | horizontal drain, vertical drain |

## Responses

- X/Y/Z shrink from bars, bore rings, and flute features.
- Bore roundness: fired ID Y vs ID Z.
- Wall thickness at head, middle, foot.
- Fundamental and six-finger scale cents error.
- Octave response, breath threshold, tone stability, and subjective playability.
- Crack/warp/sag/seam cleanup outcomes.

## Round 1 Matrix

See `data/doe-build-matrix.csv`. It contains 20 planned runs including screening and family fill-in builds.

## Round 2 Fit

Use `data/prototype-measurements.csv` and `data/shrinkage-fit.csv` to compute:

```text
shrink_axis = 1 - fired_axis / master_axis
round2_axis_scale_multiplier = target_fired_axis / measured_fired_axis
cents_error = 1200 * log2(measured_frequency / target_frequency)
```

If material or orientation creates a strong interaction, keep separate shrink factors by material/orientation rather than forcing a single global X/Y/Z value.

## mold-workflow.md

Project artifact.

# Slip-Cast Mold Workflow

## Master Strategy

1. Generate the master from the workbook/CAD dimensions using X/Y/Z scale factors.
2. Add external handling tabs, pour/drain reservoir geometry, and mold keys outside the final fired acoustic envelope.
3. Seal and polish the master. Measure master X/Y/Z dimensions before making plaster.
4. Mark datums permanently: head end, foot end, top/embouchure side, X/Y/Z axes, split line, and build ID.

## Mold Strategy

- Use a two-piece mold for G4/A4/C5 if release is clean.
- Consider a three-piece or sectional mold for D4 because length, sag, and demold stress are the main risks.
- Mold center marks or shallow dimples for holes are useful; avoid fully molded tone holes in Round 1 unless release testing proves they are clean.
- Keep registration keys away from the bore axis, embouchure edge, hole centers, and seam-cleanup surfaces.
- Include a pour/drain reservoir that can be removed without touching the fired trim target.

## Casting Controls

Record these for every run:

- slip body and batch,
- mold dry weight and mold age,
- pour time, drain time, and drain orientation,
- room temperature and humidity,
- leather-hard demold time,
- wall thickness at sacrificial rim/coupon,
- dry, bisque, and glaze firing schedules,
- fired mass, length, bore Y/Z, OD Y/Z, and note frequencies.

## Tuning-Friendly Hole Strategy

1. Cast the body with molded center marks only.
2. Cut pilot holes at leather hard, about 85% of the shrink-compensated target diameter.
3. Dry and bisque.
4. Tune by opening holes with diamond tools. Stop before final glaze.
5. Wax resist all acoustic edges before glaze.

## Failure Modes To Watch

- Long D4 body sags or twists while drying.
- Bore ovalizes differently in Y and Z.
- Mold seam intrudes into the embouchure or tone-hole region.
- Wall thickness drifts with drain time enough to change hole chimney height.
- Glaze softens, rounds, or chokes the embouchure and tone-hole edges.

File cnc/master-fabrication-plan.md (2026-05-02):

# Master Fabrication Plan

The first practical route is sealed 3D printed masters rather than CNC-cut plaster molds. The CAD model should still keep named parameters so SolidWorks/OpenSCAD can drive later configurations.

## Master Requirements

- Dimensioned from `Slip-Cast-Transverse-Flute-Family.xlsx`.
- X/Y/Z scale factors applied before export.
- Surface sealed enough that plaster will not bond or pick up layer texture.
- Bore/core strategy documented: solid master for external mold only, removable core, or split master.
- Datums engraved or marked: head, foot, top, X/Y/Z, build ID.

## Pre-Mold Checklist

- Measure master overall X, OD Y, OD Z, embouchure station, and any pilot dimples.
- Confirm no undercuts for selected mold pull direction.
- Confirm pour/drain reservoir can be cut away outside acoustic final target.
- Photograph master with scale before mold making.

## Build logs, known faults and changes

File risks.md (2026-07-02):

# Transverse Flute Risks

Scaffolded during the 2026-07-01 V5 refresh to satisfy the baseline-file
contract. All items are first-pass and unvalidated; this is an experimental
slip-cast ceramic flute lab (see README). Replace/expand with measured findings
after Round 1 firing.

## Acoustic

- Open-open flute math sets first-pass tone-hole stations only. Actual pitch
  depends on embouchure cut, bore taper, wall/undercut, and fired shrinkage —
  treat every `data/hole-schedule.csv` position as a starting point, not tuning
  authority (TBD until bisque-stage tuning). Keep holes undersized and tune up.
- Embouchure/voicing geometry is empirical and out of scope for the design
  table and the OpenSCAD envelope master; it must be refined by hand.

## Structural

- Ceramic shrinkage (X/Y/Z) is an assumption until a clay test bar is measured;
  master scaling (`master_overall_length_x_mm_initial` in family-spec.csv) is
  provisional. Firing warp/ovality on long thin tubes (D4/F4) is a real risk —
  measure straightness and bore ID after each fire (TBD).
- Thin-wall long bores may crack during drying/bisque; wall targets are
  unvalidated.

## Supply

- Live sourcing (slip, plaster, consumables) has not been checked; costs and
  lead times in sourcing.csv / bom.csv are placeholders (TBD).

## Fit/Finish

- Interior finish on a played/blown instrument must be mouth-safe; glaze/seal
  choice is unresolved (TBD).

## Process

- No physical build, tuning, firing, or validation has occurred. Do not treat
  any dimension as proven until logged in validation.csv. Remain at L2 until
  CAD, mold, and prototype tuning validation are complete.

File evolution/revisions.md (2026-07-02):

# Revision Register — transverse-flute

| Rev | Date | Parent | Delta | Downstream artifacts invalidated |
| --- | --- | --- | --- | --- |
| A | 2026-07-01 | — | Stage 0 intake of current masters (cad/slip_cast_transverse_flute_body.scad + Slip-Cast-Transverse-Flute-Family.xlsx). | none (no alpha/beta/production artifacts exist yet) |

Stage 0 only. Gate A has not been run; no Alpha compiles, vendor quotes, or production lock exist for this product.

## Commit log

2026-05-02 made by instrument-maker skill
    [Slip-Cast-Transverse-Flute-Family.xlsx, bom.csv, cut-list.csv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]
2026-05-18 Add V5 explorer authority guardrails (#3)
    * Add V5 explorer authority guardrails
    * Remove local validator path from Round 30 docs
    ---------
    [family-spec.csv, slip_cast_transverse_flute_body.scad, visual-output-register.csv]
2026-05-31 Add image-gen concept prompt; wire explorer images
2026-06-21 Wire 3 rendered concept image(s) into explorer gallery
2026-06-23 feat(wolfram): deploy interactive model + live explorer embed (#6)
    * feat(wolfram): deploy interactive model + live explorer embed
    CloudDeploy Manipulate to Wolfram Cloud (Public-Execute); regenerate
    explorer.html with live iframe. Refs tonykoop/instrument-maker#197
    * feat(wolfram): wire live explorer embed in explorer.html (Refs #197)
    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
2026-07-02 V5 packet refresh: status line, risks scaffold, provenance, evolution intake
    Rewrote broken Status line to **Status:** L2 V5 build-packet candidate (kept
    caveat prose + status table). Scaffolded missing risks.md (honest, TBD-marked).
    Added provenance rows to cad/mcp-session-log.md for the design workbook,
    data/hole-schedule.csv, fired-dimension targets, the OpenSCAD master, and the
    wolfram starter. Stage 0 evolution intake (manifest, design-intent, revisions).
    Existing cad/slip_cast_transverse_flute_body.scad kept (no rewrite); openscad
    render check pass.
    v5-validator: 4 fails -> 0 fails.
